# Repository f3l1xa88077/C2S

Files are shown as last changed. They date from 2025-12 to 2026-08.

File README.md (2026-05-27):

# CubeSat Camera System (C2S)
Relevant work for the PAST CubeSat 1 payload mission. This project focuses on developing a functioning prototype of the payload camera. The STM32U5 is used for low power performance and the image sensor is connected via DCMI.

The repository includes most aspects of the project including: documentation, hardware (Altium), mechanical 3D models, and software.

## How do I load a CubeIDE project?

The .gitignore has been modified to track critical files only, meaning most libraries and files will need to be generated again.

1. First, download the project locally: `git clone https://github.com/PerthAerospaceStudentTeam/C2S/tree/main`
2. Open the desired project in the STM32CubeIDE via: File>Import>'Projects from Folder or Archive'>Directory.
    - The project will be found in either the C2Sv0.1 or C2Sv1 directory.
3. Click the bullet icon to generate code
4. Click the hammer icon to build the project

If loaded successfully, the console should print the following to verify:

```
Finished building target: C2Sv0.1.elf
 
arm-none-eabi-size  C2Sv0.1.elf 
arm-none-eabi-objdump -h -S C2Sv0.1.elf  > "C2Sv0.1.list"
   text	   data	    bss	    dec	    hex	filename
 110972	    208	  50720	 161900	  2786c	C2Sv0.1.elf
Finished building: default.size.stdout
 
Finished building: C2Sv0.1.list

20:14:41 Build Finished. 0 errors, 0 warnings. (took 12s.137ms)

```

If any fatal errors are printed to the console, or the text in the output file is very low `text: 96` then you should address this before proceeding.

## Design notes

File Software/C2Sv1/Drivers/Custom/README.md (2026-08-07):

# C2Sv1.0 Custom Library

Overview of the custom libraries developed for the C2Sv1.0 payload, providing essential hardware abstraction and core functional interfaces.

## OV7670 Camera Module

...

## INA219BIDR Current Sense Amplifier

The INA219BIDR is a current sense amplifier (CSA) that allows you to monitor the real-time power/current consumption of the board.

### Core Variables

- `hi2c`: The I2C handle generated by CubeMX
- `INA219_HandleTypeDef`: A struct that tracks device configuration and calculated telemetry:
    - `*hi2c`: Pointer to the I2C handle
    - `current_lsb`: Calculated current LSB resolution used for unit conversion
    - `calibration`: Value written to the INA219 calibration register
    - `shunt_voltage`: Raw shunt voltage register value
    - `bus_voltage`: Raw bus voltage register value
    - `power`: Raw power register value
    - `current`: Raw current register value
    - `current_mA`: Converted load current in milliamperes (mA)
    - `power_mW`: Converted power consumption in milliwatts (mW)

### Basic Methods

| Function | Basic Description |
| :--- | :--- |
| `INA219_Setup(*INA219, *hi2c);` | Configures the chip based on settings in `INA219`. |
| `INA219_ReadAll(*INA219)` | Completes readings and conversions and stores results in `INA219`. |

### Basic Usage Example

```c
#include "ina219.h"

I2C_HandleTypeDef hi2c;
INA219_HandleTypeDef INA219_Chip;
INA219_Setup(&INA219_Chip, &hi2c);

// Read CSA Data
INA219_ReadAll(&INA219_Chip);

// Grab power (mW) and current (mA):
float power = INA219_Chip.power_mW;
float current = INA219_Chip.current_mA;

```

### Important Notes

- The INA219 gain and shunt resistance is defined in `config.h`.

## AT25xF2561C QSPI Flash Memory Driver

Custom STM32 HAL-based QSPI driver for the **Renesas AT25xF2561C** (256 Mbit / 32 MB) QSPI Flash memory chip. This driver abstracts low-level STM32 HAL QSPI commands into an intuitive API for reading, writing, and erasing data chunks specifically for C2S development.

### Core Variables

- `hospi`: The OctoSPI handle generated by CubeMX.
- `sCommand`: A command struct for OctoSPI functions.
- `QSPI_HandleTypeDef`: A struct that tracks chip information like,
    - `occupied_data`: How much data has already been written
    - `memory_size`: how many bytes the chip can hold
    - `ID_REG[3]`: The manufacturing ID
    - `*hospi`: Pointer to the OctoSPI handle
    - `*sCommand`: Pointer to the command struct
- `QSPI_DataBlock_HandleTypeDef`: A struct that tracks information for an image to be written to memory.
    - `data_size`: How large the data is in bytes
    - `*tx_pData`: Pointer to the data source
    - `*rx_pData`: Pointer to the data destination (where it will be read back into)
    - `address_block_start`: Where in QSPI the data starts
    - `address_block_end`: Where in QSPI the data ends

### Basic Methods

| Function | Basic Description |
| :--- | :--- |
| `QSPI_Init_Memory(*hospi, *sCommand, *QSPI_Memory)` | Configures the QSPI memory and populates `QSPI_Memory`. |
| `QSPI_Init_DataBlock(*DataBlock, data_size, *tx_pData, *rx_pData)` | Preps the image for transfer by populating `DataBlock` with the memory to be written `tx_pData` and the location where it will eventually be read back into `rx_pBuffer`.|
| `QSPI_Write_Data(*QSPI_Memory, *DataBlock)` | Writes `tx_pBuffer` to `QSPI_Memory`. |
| `QSPI_Read_Data(*QSPI_Memory, *DataBlock)` | Reads data into `rx_pBuffer` from `QSPI_Memory`. |
| `QSPI_Erase_Data(*QSPI_Memory, *DataBlock)` | Clears `DataBlock` from QSPI memory |

### Basic Usage Example

```c
#include "AT25xF2561C.h"

uint8_t tx_data[] = "IMAGE_DATA_001";
uint8_t rx_buffer[sizeof(tx_data)];

OSPI_HandleTypeDef hospi1;
QSPI_HandleTypeDef QSPI_Memory;
OSPI_RegularCmdTypeDef sCommand;
QSPI_DataBlock_HandleTypeDef DataBlock;

// Initialise driver hardware & configuration
QSPI_Init_Memory(&hospi1, &sCommand, &QSPI_Memory);

// Prepare data chunk (Source, Destination, Size)
QSPI_Init_DataBlock(&DataBlock, sizeof(tx_data), tx_data, rx_buffer);

// Write to memory
QSPI_Write_Data(&QSPI_Memory, &DataBlock);

// Do some stuff...

// Read back data
QSPI_Read_Data(&QSPI_Memory, &DataBlock);

// Clear data
QSPI_Erase_Data(&QSPI_Memory, &DataBlock);

```

### Important Notes

- The driver uses a **Last-In, First-Out (LIFO)** stack architecture managed by `occupied_data` inside the `QSPI_Memory` handle. It was designed around storing a single image, so if you store several items, make sure you abide by stack rules (writing/erasing in reverse order). You can read data from any position though.

- If you are finished with data, make sure to erase it, otherwise a memory leak will occur!

- At the time of `QSPI_Init_DataBlock`, you don't need to have specified `rx_pData` as it is only accessed when calling `QSPI_Read_Data`, if need be, you can leave it as `void`. The same goes for `tx_pData`.

- Data can be left in its original types as it is cast to the required type during read/write.

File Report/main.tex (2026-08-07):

\documentclass[10pt]{article}

% -----------------------
% Style Document
% -----------------------
\usepackage{style}

% -----------------------
% References
% -----------------------

\bibliography{Ref/ref}
\bibliography{Ref/stm}
\bibliography{Ref/misc}
\bibliography{Ref/datasheets}

% -----------------------
% Page Layout
% -----------------------
\pagecolor{white}
\color{black}
\geometry{a4paper, margin=1in}

% -----------------------
% Hyperref Setup
% -----------------------
\hypersetup{
    colorlinks=true,
    linkcolor=blue,
    urlcolor=cyan,
    pdftitle={CubeSat Camera System - Project Report},
    pdfpagemode=FullScreen,
}

% -----------------------
% Header/Footer Setup
% -----------------------
\pagestyle{fancy}
\fancyhf{}
\fancyhead[R]{Perth Aerospace}
% \fancyhead[C]{\bfseries \textcolor{red}{CONFIDENTIAL DO NOT RELEASE}}
\fancyhead[L]{\leftmark}
\fancyfoot[C]{C2S - Project Report}
\fancyfoot[L]{Page \thepage}
\renewcommand{\headrulewidth}{0.4pt}
\renewcommand{\footrulewidth}{0.4pt}

% -----------------------
% Begin Document
% -----------------------
\begin{document}

% -----------------------
% COVER PAGE
% -----------------------
\pagecolor[HTML]{0025A9}
\begin{titlepage}
    \centering
    \color{white}
    \vspace*{2cm}
    
     % Replace with your team logo
    
    \vspace{2cm}
    {\LARGE\bfseries Project Report\par}
    \vspace{0.5cm}
    {\Huge\bfseries CubeSat Camera System (C2S)\par}
    % \vspace{1cm}
    % {\Huge\bfseries \textcolor{red}{CONFIDENTIAL}\par}
    % {\Huge\bfseries \textcolor{red}{DO NOT RELEASE}\par}
    
    \vspace{2cm}
    {\large Abbott F. \quad | \quad Perth Aerospace Student Team\par}
    \vspace{0.25cm}
    {\large Mission Department \quad | \quad CubeSat 1 Mission\par}

    \vspace{3cm}
    This document presents all the considerations and processes towards developing the CubeSat Camera System, an undergraduate student-based project as part of the Perth Aerospace Student Team.
    The project served as a strong platform to develop sophisticated understandings of various camera subsystems.
    
    \vfill
    {\large \today \par}
\end{titlepage}

% -----------------------
% Preliminary and Reset Style
% -----------------------
\pagecolor{white}
\color{black}
\pagestyle{fancy}
\pagenumbering{roman}

% -----------------------
% Version History
% % -----------------------
% \newpage
% \section*{Document Version History}
% \begin{table}[H]        
%     \centering
%     \begin{tabular}{|l|l|p{8cm}|}
%         \hline
%     \textbf{Doc. Version} & \textbf{Date} & \textbf{Change} \\
%     \hline
%     v0.0 & Aug. 25 & Added introduction \& project details \\
%     \hline
%     v0.1 & Aug. 25 & Added version 0 system planning \\
%     \hline
%     v0.2 & Sep. 25 & Version 0 content written \\
%     \hline
%     v1.0 & Dec. 25 & Report appearance reformatted and restructured content \\
%     \hline
%     v1.1 & Mar. 26 & Content for Version 0.1 written \\
%     \hline
%     v2.0 & Apr. 26 & Report restructured, with detail added to lacking sections \\
%     \hline
%     v2.1 & May. 26 & Version 1.0 schematic content written and heading 4 added \\
%     \hline
%     \end{tabular}
% \end{table}

% -----------------------
% TOC
% -----------------------
\newpage

% 1. Ensure tocdepth is 4 (includes subsubsubsections)
\setcounter{tocdepth}{4}

% 2. Redefine how the standard paragraph entry is handled in the TOC
\makeatletter
% If the entry is a standard 'paragraph', do nothing (swallow it)
% If it's your 'subsubsubsection', it will use the \l@subsubsubsection we defined
\renewcommand{\l@paragraph}[2]{} 
\makeatother

\makeatletter
% 1. Link the titlesec class to tocloft
\newcommand{\l@subsubsubsection}{\@dottedtocline{4}{6em}{5em}}

% 2. Create the missing lengths that tocloft doesn't make automatically
\newlength{\cftsubsubsubsecindent}
\newlength{\cftsubsubsubsecnumwidth}
\makeatother

% 3. Spacing between entries
\setlength{\cftbeforesecskip}{2em}
\setlength{\cftbeforesubsecskip}{0.5em}
\setlength{\cftbeforesubsubsecskip}{0.25em}

% 4. Set Indentations (Staircase effect)
\setlength{\cftsecindent}{0em}          % Level 1
\setlength{\cftsubsecindent}{2em}       % Level 2
\setlength{\cftsubsubsecindent}{4em}    % Level 3
\setlength{\cftsubsubsubsecindent}{6em} % Level 4 (Your new level)

% 5. Set Number Widths
\setlength{\cftsecnumwidth}{2em}
\setlength{\cftsubsecnumwidth}{3em}
\setlength{\cftsubsubsecnumwidth}{4em}
\setlength{\cftsubsubsubsecnumwidth}{5em}

\tableofcontents

% -----------------------
% Table of Abbreviations
% -----------------------
\newpage
\section*{Table of Abbreviations}
    \import{Chapters/Pre/}{Abbreviations.tex}

% -----------------------
% Summary
% -----------------------
\newpage
\section*{Summary}
    \import{Chapters/Pre/}{Summary.tex}

% -----------------------
% MAIN CONTENT
% -----------------------
\newpage
\justifying
\clearpage
\pagenumbering{arabic}

\section{Introduction}\label{sec:intro}
    \import{Chapters/Intro/}{Intro.tex}

\newpage \section{C2Sv0}\label{sec:c2sv0}
    \import{Chapters/v0/}{v0.tex}

\newpage \section{C2Sv0.1}\label{sec:c2sv0.1}
    \import{Chapters/v0.1/}{v0.1.tex}

\newpage \section{C2Sv1}\label{sec:c2sv1}
    \import{Chapters/v1/}{v1.tex}

% \clearpage
% \addcontentsline{toc}{section}{References}
% \printbibliography

% \clearpage
% \appendix
% \section*{Appendices}\label{sec:appendices}
% \addcontentsline{toc}{section}{Appendices}
% \setcounter{section}{0}
%     \import{Chapters/Appendices/}{Appendices.tex}

\end{document}

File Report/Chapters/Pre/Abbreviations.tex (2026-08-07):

\begin{abbreviations}
\item[CSA] Current Sense Amplifier
\item[C2S] CubeSat Camera System
\item[LDO] Low Drop Out
\item[USB] Universal Serial Bus
\item[PAST] Perth Aerospace Student Team
\item[LEO] Low Earth Orbit
\item[PCB] Printed Circuit Board
\item[BGA] Ball Grid Array  
\item[NIR] Near Infra-Red
\item[CMOS] Complementary Metal Oxide Semiconductor
\item[CIS] CMOS Image Sensor
\item[FPGA] Field Programmable Gate Array
\item[LVDS] Low Voltage Differential Signalling
\item[IC] Integrated Circuit 
\item[ASIC] Application Specific Integrated Circuit
\item[DSP] Digital Signal Processor
\item[MCU] Micro Controller Unit
\item[SDRAM] Synchronous Dynamic Random Access Memory 
\item[SD] Secure Digital
\item[uSD] microSD 
\item[SDMMC] Secure Digital MultiMediaCard
\item[TCXO] Temperature Compensated Crystal Oscillator
\item[VDD] Voltage Drain Drain
\item[GND] Ground
\item[DGND] Digital Ground
\item[AGND] Analog Ground 
\item[GPIO] General Purpose Input Output
\item[MOSFET] Metal Oxide Semiconductor Field Effect Transistor
\item[CLK] Clock
\item[LSE] Low Speed External
\item[HSE] High Speed External
\item[LPS] Local Power Supply
\item[FPC] Flexible Printed Circuit
\item[NC] No Connect
\item[SMPS] Switched-Mode Power Supply
\item[DCMI] Digital Camera Media Interface
\item[CSI-2] Camera Serial Interface-2
\item[AT\&MWA] Advanced Technology and Manufacturing Western Australia
\item[SPI] Serial Peripheral Interface
\item[QSPI] Quad Serial Peripheral Interface
\item[OSPI] Octal Serial Peripheral Interface
\item[HiSPI] High-Speed Serial Pixel Interface
\item[I2C] Inter Integrated Circuit
\item[ADC] Analog to Digital Converter 
\item[LCD] Liquid Crystal Display
\item[EPS] Electrical Power Systems
\item[PSSR] Power Supply Rejection Ratio
\item[BOM] Bill Of Materials  
\item[C2I] C2S Camera Interface
\end{abbreviations}

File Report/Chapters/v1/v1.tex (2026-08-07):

Version 1 (v1) of C2S focuses on developing a CubeSat prototype - an early functional model built to test functionality. One major difference in this version explores a top-down systems-engineering approach, something that lacked in versions 0 and 0.1. Previously, all systems were developed in parallel to each other, meaning my component selection for the MCU was occuring at the same time I was selecting the CMOS Image Sensor (CIS). At first glance, this may seem fine, but this parallel approach fails to consider the system requirements. The CIS is the main component that everything should be designed around, not the other way around. To avoid this problem, certain goals were put in place to ensure this version was mission-oriented:

\begin{enumerate}
    \item \textbf{Systems Planning}
    \\ Consulting with manufacturers, techical documentation, and Subject Matter Experts (SMEs) to develop a trade study. Identify system requirements, map connections, data flows, and interactions between different subsystems to ensure all parts are compatible.
    \item \textbf{Comms \& Mechanical Capabilities}
    \\ Understanding and defining the camera's CubeSat limitations - dimensions, download rate, etc.
    \item \textbf{CIS Agreements}
    \\ Ensuring Non Disclosure Agreements (NDAs) are signed, so any proprietary information can be easily accessed at any time.
    \item \textbf{Component Selection}
    \\ Selecting all other components based on the system requirements.
    \item \textbf{Development}
    \\ Creating schematics, PCBs, manufacturing, etc.
\end{enumerate}

These goals were developed from my experiences of what had and hadn't worked with the previous versions, so they may not be perfect, but these are what I found to be the most important steps in camera development. Additionally, it makes writing and, in your case, reading, a lot easier to digest.

% -----------------------
% Systems Planning
% -----------------------
\subsection{Systems Planning}\label{sec:v1-planning}

    \subsubsection{Trade Study}
        \subimport{./Planning/}{Trade.tex}

    \subsubsection{System Requirements}\label{sec:v1-requirements}
        \subimport{./Planning/}{Requirements.tex}

    \subsubsection{Systems Integration Diagram}
        \subimport{./Planning/}{Planning.tex}

    \subsubsection{Capabilities}
        \subimport{./Planning/}{Capabilities.tex}

% -----------------------
% Schematic and Component Selection
% -----------------------
\subsection{Schematic Design \& Component Selection}\label{sec:v1-schematic}

    \subsubsection{MCU}\label{sec:v1-schematic-mcu}
        \subimport{./Hardware/Schematic/}{MCU.tex}

    \subsubsection{Sensor}\label{sec:v1-schematic-sensor}
        \subimport{./Hardware/Schematic/}{Sensor.tex}

    \subsubsection{Memory}
        \subimport{./Hardware/Schematic/}{Memory.tex}

    \subsubsection{microSD}\label{sec:v1-microSD}
        \subimport{./Hardware/Schematic/}{microSD.tex}

    \subsubsection{Connectors}\label{sec:v1-connectors}
        \subimport{./Hardware/Schematic/}{Connectors.tex}

    \subsubsection{Power}\label{sec:v1-schematic-power}
        \subimport{./Hardware/Schematic/}{Power.tex}

    \subsubsection{USB-C}
        \subimport{./Hardware/Schematic/}{USBC.tex}

    \subsubsection{STLINK}\label{sec:v1-schematic-stlink}
        \subimport{./Hardware/Schematic/}{STLINK.tex}

    \subsubsection{Clocks}
        \subimport{./Hardware/Schematic/}{Clocks.tex}

    \subsubsection{Button}
        \subimport{./Hardware/Schematic/}{Button.tex}

    \subsubsection{LEDs}
        \subimport{./Hardware/Schematic/}{LEDs.tex}

    \subsubsection{Test Points}
        \subimport{./Hardware/Schematic/}{TP.tex}

% -----------------------
% PCB Design
% -----------------------
\subsection{PCB Design}\label{sec:v1-pcb}

    The following sections will exclusively refer to C2Sv1.0 processor PCB. The bridge PCB consisted of a 2-layer PCB designed alongside the considerations of the processor PCB i.e., the same design considerations applied to both boards.

    \subsubsection{Stackup}
        \subimport{./Hardware/PCB/}{Stackup.tex}

    \subsubsection{Layout}\label{sec:v1-layout}
        \subimport{./Hardware/PCB/}{Layout.tex}

    \subsubsection{Routing}\label{sec:v1-routing}
        \subimport{./Hardware/PCB/}{Routing.tex}

    \subsubsubsection{Coupling}\label{sec:v1-coupling}
        \subimport{./Hardware/PCB/}{Coupling.tex}

    \subsubsection{Vias}
        \subimport{./Hardware/PCB/}{Vias.tex}

    \subsubsection{Power Pad}
        \subimport{./Hardware/PCB/}{Power Pad.tex}

    \subsubsection{Silkscreen}
        \subimport{./Hardware/PCB/}{Silkscreen.tex}

    \subsubsection{Mounting}
        \subimport{./Hardware/PCB/}{Mounting.tex}

% -----------------------
% Manufacturing
% -----------------------
\subsection{Manufacturing}\label{sec:v1-manufacturing}
    \subimport{./Manufacturing/}{Manufacturing.tex}

% -----------------------
% Software
% -----------------------
\subsection{Software}\label{sec:v1-software}
    \subimport{./Software/}{Software.tex}

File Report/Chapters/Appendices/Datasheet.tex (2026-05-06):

\subsection{Image Sensors}

\subsubsection{AR0141 Sensor}
    \begin{indentedfigure}
        
        \caption{Absolute maximum ratings of AR0141CS2M00SUEA0-DPBR found on the component datasheret, Table 26}
        \label{fig:ar0141-max}
    \end{indentedfigure}

    \begin{indentedfigure}
        
        \caption{Typical configuration for parallel pixel data interface on AR0141CS2M00SUEA0-DPBR.}
        \label{fig:ar0141-parallel-config}
    \end{indentedfigure}

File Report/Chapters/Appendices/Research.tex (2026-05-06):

% -----------------------
% WEEK 1
% -----------------------

\section{Imaging Physics and Optics}

\subsection{Focal length}

\textbf{Focal length} describes how strongly a lens focuses or diverges light. A large focal length indicates that light is being bent gradually, whereas a shorter focal length bends light at sharper angles.
A positive focal length means that the light is converging, and a negative focal length means that the light is diverging. In most photography and telescopy, longer focal length results in a greater magnification of the subject and wider focal lengths create a wider angle of view.
\nl
For thin convex lenses, the focal length can easily be measured, where the distance from the object to the lens $u$, the distance from the lens to the image $v$, and the focal length $f$ are related by \(1/f = 1/u + 1/v\).
The lens is moved until a sharp image is formed on the screen i.e., $1/u$ becomes negligible. At this point, the focal length is given by $f\approx v$.
Determining the focal length of a concave lense is more difficult abnd requires a much more systematic approach.
\nl
\begin{indentedfigure}
    \centering
    
    \caption{Thick lens diagram}
    \label{fig:lens-diagram}
\end{indentedfigure}
For a thick lens, or systems consisting of several lenses, there are several related concepts that are referred to as focal lengths:
\begin{itemize}
    \item \textbf{Effective focal length (EFL)}: The EFL is the inverse of the optical power of an optical system, and is the value used to calculate the magnification of the system. The imaging properties of the optical system can be modelled by replacing the system with an ideal, thin lens with the same EFL. It also provides a simple method for finding the nodal points without tracing rays.
    \item \textbf{Fron focal length (FFL)}: The FFL $f$ is the distance from the front focal point $F$ to the front principal plane $H$
    \item \textbf{Rear focal length (RFL)}: The RFL, $f'$, is the distance from the rear principal plane $H'$ to the rear focal point $F'$.
    \item \textbf{Front focal distance (FFD)}: The FFD, $s_F$, is the distance from the front focal point of the system, $F$, to the vertext of the first optical surface $S_1$. Sometimes this is referred to as the front focal length.
    \item \textbf{Back focal distance (BFD)}: BFD, $s'_F$, is the distance from the vertex of the last optical surface of the system $S_2$ to the rear focal point $F'$. This is sometimes referred to as the back focal length.
\end{itemize}
For an optical system in the air, the above are all the same and may be called the focal length.
\nl
For optical systems in mediums other than air or vacums, the focal length changes with the refractive index of the mediums, however, this project will not focus on this specific topic.

Camera lens focal lengths are usually specified in millimetres (mm), but some older lenses are marked with centimetres (cm) or inches.
\textbf{Focal length} $f$ and \textbf{field of view} of a lens are inversely proportional. For a standard recilinear lens,
\begin{equation}
    FOV = 2\arctan(\frac{x}{2f})
    \label{eq:fov}
\end{equation}
where $x$ is the width of the film or imaging sensor. When a photographic lens is set to "infinity", its rear principal plane is separated from the sensor or film, which is then situated at the focal plane, by the lens' focal length. Objects far away from the camera then produce sharp images on the sensor or film, which is also at the image plane.
\nl
To render closer objects in sharp focus, the lens must be adjusted to increase the distance between the rear principal plane and the film, to put the film at the image plane. The focal length $f$, the distance from the front principal plane to the object to photograph $s_1$, and the distance from the rear principal plane to the image plane $s_2$ are then related by \(1/s_1 + 1/s_2 = 1/f\).
As $s_1$ is decreased, $s_2$ must be increased. For example, consider a normal lens for a 35mm camera with a focal length of $f=50$mm. To focus a distant object ($s_1 \approx \infty$), the rear principal plane of the lens must be located at a distance $s_2=50$mm from the film plane, so that it is at the location of the image plane. To focus an object 1m away ($s_1 = 1,000$mm), the lens must be moved 2.6mm farther away from the film plane, to $s_2=52.6$mm.

\subsection{Optical power}

The \textbf{optical power} of a lens or curved mirror is a physical quantity equal to the reciprocal of the focal length, expressed in metres. A dioptre is its unit of measurement iwth dimension of reciprocal length, equivalent to one reciprocal metre, 1 dioptre = 1$m^{-1}$. E.g., a 2-dioptre lens brings parallel rays of light to focus at $1/2$ metre. A flat window has an optical power of zero dioptres, as it does not cause light to converge or diverge.

\subsection{Field of view}
The \textbf{field of view (FOV)} is the angular extent of the observable world that is seen at any given moment. In photography, the FOV is that part of the world that is visible by the camera at a particular position and orientation in spacel objects outside the FOV when the picture is taken are not recorded in the photograph. It is most often expressed as the angular size of the view cone, as an angle of view. For a normal lens focused at infinity, the diagonal FOV can be calculated with \ref{eq:fov}.
\nl
FOV is critically important in space imaging because it directly impacts what, how much, and how well a spacecraft or satellite can observe. Wider FOVs capture larger areas, whereas narrower FOVs capture more detail over a smaller area. For CubeSat applications, the FOV directly impacts the design on the system because a narrower FOV requires a longer focal length and a longer lens. If the FOV is too narrow, then deployable instruments must be investigated to break the 10x10x10cm constraint.
Wider FOVs don't require many manouvres to capture images, but narrow FOVs require precise movements to capture the correct area. Both have benefits and drawbacks.

\subsection{Aperture}
In optics, the aperture of an optical system is the hole or opening that primarily limits light propagated through the system. An optical system typically has many structures that limit pencils of light. These structures may be the edge of a lens, or a ring or other fixture that holds an optical element in place or may be a special element such as a diaphragm placed in the optical path to limit the light admitted by the system.
In general, these structures are called stops, and the aperture stop is the stop that primarily determines the cone of rays that an optical system accepts. As a result, it also determines the ray cone angle and brightness at the image point. The aperture stop generally depends on the object point location; on-axis object points at different lateral locations at the same object plane have different aperture stops (vignetted). In practice, many object systems are designed to have single aperture stop at designed working distance and field of view.
\nl
The size of the aperture stop determines the amount of light admitted by an optical system. The aperture stop also affects other optical system properties:
\begin{itemize}
    \item The opening size of the stop is one factor that affects the \textbf{depth of field (DOF)}. A smaller stop (larger f number) produces a longer DOF because it only allows a smaller angle of the cone of light reaching the image plane so the spread of the image of an object point is reduced. A longer DOF allows objects at a wide range of distances from the viewer to be in focus at the same time.
    \item The stop limits the effect of optical aberrations by limiting light such that the light does not reach edges of optics where aberrations are usually stronger than the optics centers.
    \item The stop determines whether the image will be vignetted. Larger stops can cause the light intensity reaching the film or detector to fall off toward the edges of the picture, especially when, for off-axis points, a different stop becomes the aperture stop by virtue of cutting off more light than did the stop that was the aperture stop on the optic axis.
    \item The stop location determines the telecentricity (the entrance or exit pupil, or both, at infinity). If the aperture stop of a lens is located at the front focal plane of the lens, then it becomes image-space telecentricity, i.e., the lateral size of the image is insensitive to the image plane location. If the stop is at the back focal plane of the lens, then it becomes object-space telecentricity where the image size is insensitive to the object plane location. The telecentricity helps precise two-dimensional measurements because measurement systems with the telecentricity are insensitive to axial position errors of samples or the sensor.
\end{itemize}
In astronomy, the opening diameter of the aperture stop (called the aperture) is a critical parameter in the design of a telescope. Generally, you would want the aperture to be as large as possible, to collect the maximum amount of light from the distant objects being imaged. The size of the aperture is limited, however, in practice by considerations of its manufacturing cost and time and its weight, as well as prevention of aberrations (as mentioned above).
\nl
In photography, the aperture stop of a photographic lens can be adjusted to control the amount of light reaching the image sensor. In combination with variation of shutter speed, the aperture size will regulate the image sensor's degree of exposure to light (this is called the \href{https://photographylife.com/what-is-exposure-triangle}{exposure triangle}). A device called a diaphragm usually serves as the aperture stop and controls the aperture. The diaphragm serves much like the iris of the eye. Reducing the aperture size provides less light to the sensor and increases the depth of field, which describes the extent to which subject matter lying closer than or farther from the actual plane of focus appears to be in focus.
The lens aperture is usually specified as an f-number, the ratio of focal length to effective aperture diameter. In photography, \textit{one f-stop} refers to a factor of $\sqrt{2}$ change in f-number which corresponds to a $\sqrt{2}$ change in aperture diameter, which in turn corresponds to a factor of 2 change in light intensity (by a factor 2 change in the aperture area).
The amount of light captured by an optical system is proportional to the aera of the entrance pupil that is the object space-side image of the aperture of the system, equal to:
\[
Area = \pi (\frac{D}{2})^2 = \pi (\frac{f}{2N})^2
\]
Where the two equivalents are related by the f-number $N=f/D$, with focal length $f$ and entrance pupil diameter $D$.

\subsection{Key Trade-Offs in Earth Observation Imaging}
The interplay between motion blur, exposure time, and depth of field is a critical consideration in Earth observation imaging. Adjusting one parameter often impacts the others, necessitating a balance to achieve optimal image quality.
\nl
\textbf{Motion Blur vs. Exposure Time}: Longer exposure times capture more light, reducing noise, but they increase the risk of motion blur, especially in satellite imaging where relative motion is significant. Conversely, shorter exposure times minimise motion blur but may lead to darker images since they capture less light. The maximum exposure time to minimise motion blur can be found by \(t=\frac{rc}{v}\), where $r$ is the spatial resolution, $c$ is a factor of the motion blur (between 0 and 1) and $v$ is the speed of the CubeSat.
\nl
\textbf{Exposure Time vs. Noise}: Reducing exposure time to combat motion blue can result in increased image noise, as the sensor has less time to collect photons. This trade-off is particularly challenging in low-light conditions or when high image clarity is required.
\nl
\textbf{Aperture vs. Exposure}: A wider aperture allows more light, enabling shorter exposure times and reducing motion blur. However, it decreases the depth of field, potentially causing parts of the image to be out of focus. A narrower aperture increases depth of field but required longer exposure times.
\nl
Advanced sensors with higher sensitivity (quantum efficiency) can mitigate some of these trade-offs by allowing shorter exposure times without significantly increasing noise. Techniques such as motion compensation and image stabilisation can help reduce the effects of motion blur without altering exposure settings. Image processing algorithms can correct for certain artifacts like noise and blur, but they have limitations and cannot fully compensate for suboptimal capture settings.

\subsection{C, CS and S-Mount Camera Lenses}
Lens mounts are the mechanical interfaces that attach a lens to a camera and set the correct distance for focus. When designing compact or modular camera systems, three primary lens mount types are commonly considered: \textbf{M12 (S-Mount), CS-mount}, and \textbf{C-mount}. Each has distinct mechanical and optical characteristics, making them suitable for different use cases.
\nl
The \textbf{M12 mount}, also known as the \textbf{S-mount}, is the smallest and lightest of the three. It uses a 12mm diameter thread and has no fixed flange focal distance (FFD), typically relying on adjustable back-focus. M12 lenses are compact and inexpensive, making them ideal for small embedded systems like drones or hobby cameras. However, their image quality is generally lower due to smaller optics, and they usually support sensor formats up to 1/2" or 1/1.8".
\nl
The \textbf{CS-mount} is a more robust, standardised system commonly used in CCTV and industrial vision. It shares the same thread as the C-mount (1"-32 UN), but has a shorter FFD of 12.5mm, which means lenses sit closer to the sensor. CS-mount cameras can use both CS and C-mount lenses, giving it some flexibility. These lenses support larger sensors and generally offer better image quality than M12 lenses.
\nl
The \textbf{C-mount} is the most optically capable of the three, also using the 1"-32 UN thread0 but with a 17.526mm FFD. C-mount lenses are larger, heavier, and typically of higher optical quality, supporting sensor sizes up to 1" or more. They are often used in scientific imaging, space optics, and high-end industrial systems. However, their size and mass can be a limiting factor in space-constrained environments.

\subsection{Autofocus vs. Fixed-focus Lenses}
Embedded vision systems rely heavily on the capabilities of their lenses. The lens's optical properties, such as its focal length, aperture, and FOV, dictate the clarity, depth, and breadth of the captured image. These parameters, along with sensor size and resolution, directly impact the systems' ability to analyse and interpret visual data.
\nl
A \textbf{fixed-focus lens} comes with a determined and unchangeable focal length. Once set, this focus remains constant and doesn't adjust based on changes in the scene or the distance of the target object. Such lenses are calibrated during the design or manufacturing phase for a specific application or distance, ensuring optimal clarity for that designated range.
Fixed-focus lenses are advantageous in scenarious that demand consistent and predictable imaging results. When objects are presented at a consistent distance from the camera, fixed-focus lenses offer stability and repeatability. For the CubeSat mission, it is highly likely we will used a fixed-focus lens since we will only be taking one type of image at a consistent orbital distance.
\nl
An \textbf{autofocus (AF)} lens can automatically adjust its focus based on the scene. Unlike manual focus lenses, which require a predefined focus set during the design or intial setup, autofocus lenses dynamically adjust to ensure the targeted subject or region of interest remains sharp. It is achieved through sensors and algorithms that detect the optimal focus point, allowing the lens to modify its focus in real time.
AF lenses offer a high level of adaptability and accuracy in embedded vision systems, ranging from industrial automation to medical devices. They can continuously adjust to provide sharp images.
\nl
The selection criteria for AF vs. fixed-focus lens includes:
\begin{itemize}
    \item \textbf{Proximity}: The distance between the camera and target plays a crucial role in selecting a lens, impacting the clarit and precision of captured images. AF lenses are preferable for fluctuating distances, especially from a close 10cm to an endless range, allowing dynamic adjustments. However, a fixed-focus lens is better suited for a set distance, ensuring consistent imagery without any adjustments.
    \item \textbf{Depth of Field (DoF)}: Cameras with autofocus lenses offer broader field depths than their fixed-focus counterparts. But sometimes, depending on the use case, a fixed-focus camera lens may be required, as some applications do not need broader field depths.
    \item \textbf{Lighting Conditions}: This directly influences the clarity of photos. Autofocus lenses perform better under low lighting, with some fine-tuning to provide further clarity. However, under brightly lit conditions, a fixed-focus camera lens can offer clear images within its preset range.
    \item \textbf{Rate of capture}: Fixed-focus lenses typically work faster than their AF counterparts, as they lack the need for focus adjustments. Their design prioritises speed over adaptability, making them efficient for certain tasks. Consequently, if an application demands fast image cpature without interruptions, a fixed-focus lens is the recommended choice. It ensures consistent, rapid imaging without the potential lag of autofocus lens adjustments.
    \item \textbf{Adaptability}: The camera lens' versatility is also a deciding factor. Autofocus lenses perform better in low-light scenarios, with some customisation. However, fixed-focus camera lenses can offer clear images within their preset range under brightly lit conditions, where light is stable and abundant.
\end{itemize}
With the CubeSat mission in mind, these considerations are critically important:
\begin{itemize}
    \item \textbf{Size and Weight}: AF lenses require motors, actuators, and additional housing, all of which increase the overall size and mass. Fixed-focus lenses are typically much smaller and lighter.
    \item \textbf{Power Consumption}: AF systems consume electrical power to operate motors and sensors needed for focusing. Fixed lenses use no power once installed.
    \item \textbf{Reliability}: Moving parts in AF lenses can jam, degrade, or fail over time. A foxed-focus system is mechanically simple and has fewer points of failure, making it much more suitable for long-duration, unattended missions.
    \item \textbf{Launch Survivability} The vibration during rocket launch can damage sensitive optical systems. AF components may loosen or break. Fixed-focus lenses are more robust and more likely to survive launch intact.
    \item \textbf{Autonomy and Complexity}: AF systems require logic to detect blur, estimate distance, and control motors. This demands more computing resources and software development. Fixed-focus lenses avoid this entirely, simplifying the onboard system and reducing potential bugs.
\end{itemize}
As previously mentioned, it is very likely the CubeSat mission will utilise a fixed-focus lens. Future missions may provide scope to consider AF systems, however, since the projected outcomes for the first CubeSat mission involve functionality of the core sub-systems, a fixed-focus lens will be best suited to the mission.

\subsection{Wide and vs. Telephoto Imaging}
\textbf{Telephoto imaging} refers to a narrow FOV with high magnification (useful for capturing small details or distant targets), whereas \textbf{wide-angle imaging} provides a broader FOV (useful for capturing a larger area).
\nl
Telephoto lenses require a much larger focal length which is difficult to achieve in a CubeSat form factor. There have recently been \href{https://digitalcommons.usu.edu/cgi/viewcontent.cgi?referer=&httpsredir=1&article=3059&context=smallsat}{developments} into deployable telephoto lenses to achieve extremely high levels of detail up to 1 metre per pixel. These missions can typically use a 2U or larger form factor, so reaching a relatively high level of spatial resolution (50-100 metres per pixel) is a strong possibility for the CubeSat mission. Deployable telescopes may be out of scope for this first CubeSat mission, however, they do demonstrate that the task is possible.
Since longer focal lengths require a higher frame stability, more power may need to be directed to the ADCS. Telephoto imaging means the camera must be pointed very precisely at the target. Error in attitude can cause motion blur, data loss or missing the target entirely. Achieving this requires a longer stabilisation time after manouvres to confirm attitude.
Custom telephoto lens systems require more planning, budget, stricter testing and longer development times because of the increased scope.
\nl
\textbf{Wide angle lenses} have a much shorter focal length and their optical systems are much more compact. The wider FOV loses detail since the spatial resolution is much larger, however, they capture a larger area.
These lenses tolerate pointing errors because of the low spatial resolution. If the CubeSat isn't facing the target by a couple degrees, or is slowly rotating, the image will most likely be unaffected because the wide FOV tolerates more errors e.g., accidentally pointing at Mandurah instead of Perth doesn't matter if we are capturing an image from Esperance to Shark Bay.
Additionally, COTS wide angle cameras are cheap, small and readily available which will make integration much easier.
\nl
Since the file size and thermal management of both camera systems would be similar, it is not a critical comparison consideration.

\subsection{Optical distortions and corrections}
Distortion is specified as a percentage of the field height. Typically, $\pm 2\%$ to $3\%$ distortion is unnoticed in a vision system if measurement algorithms are not used. In simple lenses, there are two main types of distortion: negative, barrel distortion, where points in the FOV appear too close to the center; and positive, pincushion distortion, where points are too far away. Barrel and pincushion refer to the shape of the field when distorted, shown in \ref{fig:lens-distortion}.
\begin{indentedfigure}
    \centering
    
    \caption{An illustration of positive and negative distortion.}
    \label{fig:lens-distortion}
\end{indentedfigure}
These are usually referred to as \textbf{geometric distortions}, because straight lines appear curved or displaced especially at wide angles or at the edges of the FOV.
Distortion is calculated simply by relating the actual distance (AD) to the predicted distance (PD) of the image using \ref{eq:distortion}.
\begin{equation}
D(\%)=\frac{AD-PD}{PD}\times100\%
    \label{eq:distortion}
\end{equation}
These usually occur when the magnification decreases with distance from the center and is common in wide-angle and cheap lenses. Fortunately, some software algorithms like OpenCV's undistort() can provide optical correction (some applications such as Photoshop and Matlab have lens profiles in the software).
\nl
\subsubsection{Fisheye Distortion}
\textbf{Fisheye Distortion} is an extreme wide-angle effect where lines are heavily cirved, giving a hemispherical apperance. This is usually intentional for fish-eye lenses to capture extremely wide FOVs of $>160$\textdegree. Sometimes the effect is desirable, but it can be correct via software remapping using known distortion models (e.g., Photoshop has options to reverse fish-eye lens effects).
\nl
Optical aberrations are performance deviations from a perfect, mathematical model. It is important to note that they are not cause by manufacturing flays, physical, optical, nor mechanical. Rather, they are inherent in lens design and are due to diffraction, refraction, and the wave nature of light. As such, there is no perfect lens.
Effects from various aberrations in a lens design are ultimately seen in performance and affect modulation transfer function (MTF), spot size, telecentricity, DOF, and others. Aberration theory is an abstract and complex subject. Understanding how aberrations affect performance is important for success with an application.
Whilst aberration theory is a vast subject, basic knowledge of a few fundamental concepts can ease understanding: spherical, astigmatic, field curvature and chromatic.
\nl
\subsubsection{Spherical Aberration}
\textbf{Spherical Aberration} refers to rays focusing at different distances depending on where they interact with the lens and is a function of aperature size. To describe spherical aberration, the incident angle of light must be known. This angle occurs where light rays strike the curved surface of a lens and is the angle between the ray and the surface. The steeper the incident angle, the more light will be refracted.
\begin{indentedfigure}
    \centering
    
    \caption{An example of spherical aberration. The light incident upon the edges of the lens focuses more quickly due to their higher angle of incidence. Note that rays closer to the optical axis (smaller angle of incidence refract less).}
    \label{fig:spherical-aberration}
\end{indentedfigure}
\ref{fig:spherical-aberration} shows that as the parallel rays in object space collide with the lens, the incident angle increases the farther up they hit on the lens's surface. Image quality from the lenses with large apertures are more likely to suffer from spherical aberration, because of this larger angle of incidence. Lenses that suffer from spherical aberration can be improved by increasing the f-stop by closing the iris. Closing the iris too much causes diffraction to limi performance sooner. Optical designs that include high index glass or additional elements are used to correct spherical aberration in a fast (small f-stop) lens; these designs reduce the amount of refraction at each surface and, with it, the amount of spherical aberration. However, this increases the size, weight, and cost of the lens assembly.
\nl
\subsubsection{Astigmatism}
\textbf{Astigmatism} is a function of field angles. To summarise, astigmatic aberration occurs when a lens must perform over a wide field, but the performance in the direction of the field is reduced compared to the performance orthogonal to the field (either sagittal or tangential, respectfully). If one looks at a series of bars that are half horizontal (tangential) and half vertical (sagittal), the bars in one direction will be in focus, but the bars in the other will be out of focus.
\begin{indentedfigure}
    \centering
    
    \caption{Off-axis asymmetry. Note that the tangential and sagittal points of focus are different.}
    \label{fig:astigmatism}
\end{indentedfigure}
This is caused by the fact that the rays that are away from the center of the object, do not pass through rotationally symmetric surfaces like the on-axis rays do in \ref{fig:astigmatism}. To correct this, two things must occur: lens designs must be symmetric about the aperture and field rays must have low incident angles. Keeping a design symmetric leads to forms that are like a double gauss lens. Note that symmetric designs prevent the use of telephoto or reverse telephoto designs, which can cause long focal length designs to be large and short focal length designs to have small back focal lengths. Reducing the angles of incidence, much like for spherical aberration, requires higher index glasses and additional elements, leading to an increase in lens size, weight, and cost. The simplified definition used here intentionally combines the effects of astigmatism and coma for ease of understanding.
\nl
\subsubsection{Field Curvature}
\textbf{Field Curvature} is the aberration that describes the amount in which the image plane curves due to the curvature in the lens design. This aberration is caused by the sum of the focal lengths of the lens elements in the system (multiplied by the refractive indices) not equalling zero. If the sum is positive (typical for an imaging lens), the image plane will have a concave curvature. Since curving the image plane is almost never an option for a machine vision lens, the optical designer must insert negative powered corrective elements to reduce this sum. This makes lenses longer and forces a negative lens to be close to the image plane, reducing the lens's back focal length.
\begin{indentedfigure}
    \centering
    
    \caption{A field curvature example showing the non-planer surface of best focus.}
    \label{fig:curvature}
\end{indentedfigure}
\subsubsection{Chromatic aberration}
\textbf{Chromatic aberration} occurs when light of different wavelengths focus at different points since the refractive index of glass varies based on the wavelength of light. Lenses using longer wavelengths of light have relatively longer focal lengths than lenses using shorter wavelengths. Because the dispersion of a glass determines the refractive power of the glass at different wavelengths, chromatic aberration can be removed by designing an imaging lens that contains both positive and negative lenses made using glasses with different dispersions. This is shown in \ref{fig:chromatic}, which compares a singlet to an achromatic doublet lens.
\begin{indentedfigure}
    \centering
    
    \caption{A comparison of singlet and doublet lens spots.}
    \label{fig:chromatic}
\end{indentedfigure}
A downside to such a design is the increase in the number of lens elements used. To reduce the aberration, lower index lenses are needed to correct spherical and astigmatic, and chromatic aberrations; if corrections for spherical, astigmatic, and chromatic aberrations must be done, additional lens elements are needed. Additionally, the most desirable glasses for color correction often have properties that make them more expensive and difficult to manufacture. Minimising chromatic aberration by using monochromatic light has considerable savings in cost and complexity.
\nl
\subsubsection{Chromatic Focal Shift}
\textbf{Chromatic Focal Shift} is a type of chromatic aberration, chromatic focal shift describes how different wavelengths focus along different longitudinal positions (along the optical axis). The goal of most imaging lens designs is to have all desired wavelengths focus on the same plane (where the sensor is located). It is physically impossible to get a singular focus plane over a wide spectral range. However, it is possible to come close. If the wavelengths are focused closer to the same plane, fewer issues will be observed in the image.
\begin{indentedfigure}
    \centering
    
    \caption{Chromatic focal shift curve for an achromatic lens.}
    \label{fig:achromat}
\end{indentedfigure}
\ref{fig:achromat} shows a chromatic focal shift curve. Since this is an example of an achromatic lens design, two wavelengths are focused on the same plane. The y-axis shows changing wavelength from short to long (blue to red in the visible spectrum). The vertical black line represents a plane that could be the sensor location, and the x-axis shows the distance away from that location. The blue curved line shows the relative location of the best focus as a function of wavelength. The curve verifies that this design is achromatic since even if moved slightly to the left or right, the black line intersects the blue curve at only two points/wavelengths.
The blue, green, and red dots represent wavelengths associated with common 470nm, 520nm, and 630nm (blue, green, and red) LEDs. Notice the green dot focuses to the left of the sensor plane, while the red and blue dots focus to the right; this is the most balanced position of focus of the lens system if all the wavelengths or white light (which encompasses all wavelengths) are used. This design displays non-ideal image quality, as none of the wavelengths are truly in focus. If only one wavelength is used, the performance will improve since balancing effects used for the other wavelengths are eliminated. While this example demonstrates that red and blue can be balanced, this is not always true. Most lens designs are achromatic, but for very small pixels, this can be an issue.
\begin{indentedfigure}
    \centering
    
    \caption{Chromatic focal shift for an apochromatic lens.}
    \label{fig:apochromat}
\end{indentedfigure}
Shown at the same scale as \ref{fig:achromat}, \ref{fig:apochromat} shows an apochromatic lens. An apochromatic lens is designed to focus three wavelengths on the same plane. While this is a far more complicated design, it allows for superior balancing across the wavelength spectrum. As shown, all three LED colors can be brought to focus on the same sensor plane allowing for superior image quality. Apochromatic lens designs have high performance, but low versatility and work well over a smaller range of magnifications and WDs. Additionally, these are often high-cost designs due to additional elements made of expensive materials. Many high-end, high-magnification objectives (such as microscope objectives) are apochromatic.

\subsection{Filter types}
\subsubsection{IR-cut filters}
Generally, systems such as CMOS and CCD cameras capture accurate images in daylight. Their sensors can detect near-infrared light that is invisible to the human eye. Whilst this can be an important feature for night-vision recording, the infrared light distorts the colours of recorded images during daytime hours.
\\
\textbf{Infrared (IR) cut filters} are a mechanical shutter design that blocks or delivers the IR, providing a high quality image with true colour reproduction, irrespective of day or night. To make images more similar to waht humans can view, most OEM cameras are fitted with an IR-cut filter which allows only the visible light to pass through, thereby reflecting the unwanted IR.
\begin{indentedfigure}
    \centering
    
    \caption{Comparison of images with and without IR-cut filter.}
    \label{fig:IR-cut}
\end{indentedfigure}
\begin{indentedfigure}
    \centering
    
    \caption{Placement of IR-cut filter in a camera}
    \label{fig:IR-cut-diagram}
\end{indentedfigure}
The filter is controlled by a motor or with the help of an electromagnet. When the IR filter is turned on during daytime, it helps to block IR, letting only the visible light pass through. This process is known as \textbf{True Day Night (TDN)} because it delivers true colour images during the day and black and white or night vision images at night. It ensures that the image colours are not disturbed and generates a true representation of colours, as seen by naturally by the human eye.
When the IR filter is turned off during the night or in low-light confitions, it helps IR and other forms of light to reach the CCD/CMOS sensor. The image sensor, in turn, absorbs enough light, and the camera turns back to black-and-white mode, which is more sensitive to IR light.
\nl
There are three main reasons to use an IR-cut filter:
\begin{itemize}
    \item \textbf{To avoid colour distortion}. Generally, IR light leads to colour distortion during the day. To solve this issue, an IR-cut filter is used to keep the IR light disturbance out of the image sensor during the day. When the light falls below a certain level, the filter automatically swivels out of the way so that the IR light does hit the image sensor. Also, the camera switches to black-and-white mode to use the IR light optically.
    \item \textbf{To achieve realistic colours}. The IR-cut filter in a colour camera can achieve realistic colours in white light. In general, the colour spectrum viewed by the human eye is quite limited compared to the sepctrum viewed by a CCD camera. Especially, the difference in sensitivity is significant in the near IR region of the spectrum. If an IR-cut filter is not used, a huge amount of infrared light will appear, resultin in strange colours.
    \item \textbf{To achieve colour correction in lenses}. In many cases, it is difficult to design imaging optics covering both the visible sepctrum and the near IR spectrum. Therefore, many lenses have different depths of focus for the visible and the IR spectrum. In such cases, the IR-cut filter cuts away a significant amount of the collected light and achieves colour correction in lenses.
\end{itemize}
\begin{indentedfigure}
    \centering
    
    \caption{Comparison of standard lens and IR-corrected lens}
    \label{fig:IR-day-night}
\end{indentedfigure}
\subsubsection{Bayer filters vs. monochrome sensors}
\textbf{Bayer filters} and \textbf{monochrome sensors} are distinct approaches to image capture in digital cameras. Bayer filters are used in standard colour cameras to capture colour information, while monochrome sensors capture only light intensity without colour information. This leads to differences in image quality, low-light performance, and resolution.
\nl
Bayer filters, also known as \textbf{Colour Filter Arrays (CFAs)} are used to create colour images. They consist of a mosaic of red, green and blue filters arranged over the sensor's pixels.
Each pixel in a Bayer sensor captures only one colour component. To create a full-colour image, the missing colour information for each pixel is interpolated from its neighbours, a process that can introduce some softness or artifacts.
Bayer filters are the standard for most digital cameras and camcorders.
\begin{indentedfigure}
    \centering
    
    \caption{Simple Bayer sequence of RGGB.}
    \label{fig:bayer-sequence}
\end{indentedfigure}
As shown in \ref{fig:bayer-sequence}, bayer filters use a RGGB sequence to emulate the vision of the human eye since we are more sensitive to green light compared to red and green.
Unfortunately, the colour filter array reduces the amount of light reaching the sensor, potentially impacting low-light performance. Interpolation can also slightly reduce sharpness compared to monochrome sensors.
Fortunately, they provide the ability to capture full colour information in a single shot.
\nl
Monochrome sensors only capture the intensity of light without any colour filtering. Because they capture all the light information at each pixel, monochrome sensors can provide higher resolution and finer detail compared to Bayer sensors, especially in low-light conditions.
Without the light-absorbing colour filters, monochrome sensors are more sensitive to light, making them better in low-light situations. They are favoured in scientific, industrial and specialised applicants where colour information is not essential.
Although they capture only greyscale images, monochrome sensors can also be used with filters to create different black and white looks. They also offer greater flexibility in post-processing for contrast and tone adjustments.
Since there is no need for colour interpolation, monochrome sensors can offer sharper images with more detail.

\subsubsection{Bandpass \& ND filters}
\textbf{Bandpass} and \textbf{Neatural Density (ND)} filters are crucial in imaging missions for enhancing image quality, controlling light, and enabling specific observations. Bandpass filters isolate specific wavelengths of light, improving contrast and clarity, while ND filters reduce overall light intensity, preventing sensor saturation in bright conditions and allowing for longer exposure times.
\nl
Bandpass filters selectively transmit a specific range of wavelengths while blocking others, which is useful for isolating specific features or phenomena in an image. Some of the applications include:
\begin{itemize}
    \item \textbf{Astronomy}. Enhancing contrast in images of nebulae and galaxies by isolating specific emission lines.
    \item \textbf{Fluroescence microscopy}. Isolating excitation and emission wavelengths to visualise specific biological molecules.
    \item \textbf{Machine vision}. Improving contrast and resolution by reducing chromatic aberration and selecting relevant wavelengths.
    \item \textbf{Environmental monitoring}. Detecting specific gases or pollutants based on their spectral signatures.
    \item \textbf{Remote sensing}. Identifying materials and vegetation based on their unique spectral reflectance.
\end{itemize}
Some of the benefits include:
\begin{itemize}
    \item \textbf{Improved Signal-to-Noise (SNR) ratio}. By blocking unwanted light, bandpass filters enhance visibility of the desired signal.
    \item \textbf{Enhanced contrast and clarity}. Isolating specific wavelengths allows for clearer visualisation of target features.
    \item \textbf{Precise spectral analysis}. Bandpass filters are essential for spectroscopic analysis and identifying chemical compositions.
\end{itemize}

ND filters reduce the intensity of all wavelengths of light equally, allowing for slower shutter speeds or wider apertures in bright conditions. Some of the applications include:
\begin{itemize}
    \item \textbf{Daytime photography and videography}. Preventing overexposure in bright sunlight and enabling creative effects like motion blur.
    \item \textbf{Long-exposure photography}. Allowing for long exposures in daylight to capture light trails or smooth water.
    \item \textbf{Drone imaging}. Controlling exposure in aerial photography and videography.
\end{itemize}
Some of the benefits include:
\begin{itemize}
    \item \textbf{Controlled exposure}. ND filters allow for proper exposure in bright conditions, preventing sensor saturation.
    \item \textbf{Creative effects}. Enabling long exposures and motion blur in bright environments.
    \item \textbf{Sensor protection}. Reducing light intensity can help protect the sensor from damage in very bright conditions.
\end{itemize}

In some imaging missions, bandpass and ND filters are used together. For example, in drone imaging, a bandpass filter might be used to isolate secific spectral band for vegetation analysis, while an ND filter could be used to control the overall exposure level.
Dual bandpass filters can be used to optimise imaigng for both visible and near-IR light.

% -----------------------
% WEEK 2
% -----------------------

\section{Image Sensors \& Signal Conversion}
\subsection{Photodiodes}
Photodiodes are semiconductor devices that convert light into electrical current. When light, specifically photons, strike the photodiode's p-n junction, they generate electron-hole pairs. These carriers are then separated by the electric field in the depletion region, creating a photocurrent. The amount of current produced is directly related to the intensity of the incident light. 
\begin{indentedfigure}
    \centering
    
    \caption{Photodiode diagram}
\end{indentedfigure}
Photodiodes can operate in two main modes:
\\
\textbf{Photovoltaic mode}. In this mode, no external voltage is applied, and the photodiode generates a voltage when exposed to light.
\\
\textbf{Photoconductive mode}. A reverse bias voltage is applied, increasing the depletion region and enhancing the photodiode's sensitivity and response speed.

\subsubsection{Photoelectric effect}
The photoelectric effect is the emission of electrons from a material caused by electromagnetic radiation such as ultraviolet light. Electrons emitted in this manner are called photoelectrons. The phenomenon is studied in condensed matter physics, solid state, and quantum chemistry to draw inferences about the properties of atoms, molecules and solids. The effect has found use in electronic devices specialised for light detection and precisely timed electron emission.
\nl
The photoelectric effect is the core principle of how digital cameras operate. When a photon strikes the photodiode, it transfers energy to electrons in the material (typically silicon). This is a direct application of the photoelectric effect. These freed electrons are collected and stored as an electric charge in a potential well. The more photons hit the pixel, the more electrons accumulate, this is how brightness is measured. The camera's electronics read out the stored charges and convert them to digital values, which are processed to form the final image.

\subsubsection{Quantum efficiency}
\textbf{Quantum efficiency (QE)} in camera sensors refers to the percentage of incoming photons that are successfully converted into electrons, which are then used to form an image. A higher QE indicates a more efficient sensor, meaning it can produce a stronger signal from the same amount of light, leading to better image quality, particularly in low-light conditions. 
\nl
QE is a crucial factor in determining a camera's sensitivity, especially in low-light situations. Higher QE leads to better signal-to-noise ratio, meaning a clearer, less noisy image, especially when light levels are low.
QE varies with the wavelength of light. Some sensors are more efficient at certain wavelengths than others. Different sensor technologies (e.g., CCD, CMOS, back-illuminated, front-illuminated) have varying QE characteristics. Back-illuminated sensors generally have higher QE than front-illuminated sensors, but they are also more expensive. 

\subsubsection{Charge accumulation}
In camera sensors, \textbf{charge accumulation} is the process where light is converted into electrical charge within tiny light-sensitive elements called pixels. This charge is accumulated proportionally to the intensity of the light striking each pixel during the exposure time. The accumulated charge is then read out and processed to create the final image. 
\nl
In \textbf{Charge-Coupled Device (CCD)} sensors, the accumulated charge is transferred through the sensor's grid, like a bucket brigade, to a common readout circuit. 
In \textbf{Complementary Metal-Oxide-Semiconductor (CMOS)} sensors, the charge at each pixel is converted to a voltage, and then the signal is read out. 
The accumulated charge values from all pixels are then read out, converted into digital data, and processed by the camera's electronics to form the final image. 

\subsubsection{Full well}
A \textbf{full well} in an image sensor is the amount of charge that can be stored within an individual pixel without the pixel becoming saturated. It is dependent on the pixel size of the sensor and the camera operating voltages.
\begin{indentedfigure}
    \centering
    
    \caption{Three different cameras with 2.5, 5 and 10 µm pixels. The full well capacity increases with increasing pixel size.}
\end{indentedfigure}
Different sized pixels are used for different applications. Whilst a smaller pixel size increases the number of pixels that can be placed on a sensor, the number of photons each pixel can detect is also reduced for the same photon flux, and therefore quantum efficiency tends to be reduced. Since fewer photons are collected the signal is lower and so the signal-to-noise ratio is reduced.
On the other hand, if the sensor is too big, or contains too many pixels, a much greater computational power is required to process the output information, decreasing image acquisition. It is important to select a camera sensor that balances the pixel size requirements with the acceptable noise levels for the application.
Generally, larger pixel sizes are used for achieving a higher sensitivity whilst smaller pixels are used for obtaining a higher spatial resolution.
\nl
Below is a diagram of a general pixel - not specific to any sensor type. Please refer to this figure for concepts discussed later such as microlenses.
\begin{indentedfigure}
    \centering
    
    \caption{See caption above.}
\end{indentedfigure}

\subsubsection{Saturation}
At the saturation point, pixels are unable to store additional charges, so instead this charge is spread into neighboring pixels. This causes saturation within neighboring pixels also. This spread of charge is called blooming and is visualized as a white vertical streak or smear on the image. During readout, the excess electrons from the saturated signal are moved down the sensor, resulting in a vertical smear.

\subsubsection{Signal to Noise Ratio}
The \textbf{Signal to Noise Ratio (SNR)} of a camera describes the ratio between the light signal and the image noise.
\\
The perfect camera sensor would convert a known amount of light into a precisely predictable output voltage. Unfortunately, this perfect sensor does not exist in reality. Due to temperature conditions, electronic interference or similar, sensors do not convert light with 100\% accuracy.
Sometimes the output voltage is slightly higher than expected and sometimes slightly lower. The difference between the expected ideal signal and the signal actually received is referred to as noise.
\nl
The signal-to-noise ratio is usually specified as a factor, for example: 20:1, 30:1, etc. Alternatively, the signal-to-noise ratio can also be expressed in decibels (dB).
The formula for calculating the signal-to-noise ratio in dB is: $\texttt{SNR} = 20* \log (\texttt{signal}/\texttt{noise})$.
\begin{indentedfigure}
    \centering
    
    \caption{The signal-to-noise ratio: from low (left) to high (right) signal-to-noise ratio.}
\end{indentedfigure}
Once noise has become part of a signal, it can no longer be filtered or reduced. It is therefore advisable to take precautions to reduce the generation of noise, such as:
\begin{itemize}
    \item Use high-quality sensors and electronic devices in your camera.
    \item Use a good electronic architecture in the development of your camera.
    \item Lower the temperature of the sensor and other analog devices in your camera.
    \item Shield against interfering environmental conditions that affect the signal (e.g. by using shielded cables).
\end{itemize}
Camera users often increase the gain setting of their camera thinking that they are improving the signal-to-noise ratio. Since increasing the gain increases both the signal and the noise, the signal-to-noise ratio does not change significantly when the gain is increased. Gain is not an effective means of increasing the information content of the signal. Gain only changes the contrast of an existing image.

\subsection{Sensors}
\subsubsection{CCD}
A \textbf{charge-coupled device (CCD)} is an integrated circuit containing an array of linked, or coupled, capacitors. Under the control of an external circuit, each capacitor can transfer its electric charge to a neighbouring capacitor. CD sensors are a major technology used in digital imaging.
\begin{indentedfigure}
    \centering
    
    \caption{Block Diagram of a Charge-Coupled Device (CCD).}
\end{indentedfigure}
In a CCD image sensor, pixels are represented by p-doped metal-oxide-semiconductor (MOS) capacitors. These MOS capacitors, the basic building blocks of a CCD, are biased above the threshold for inversion when image acquisition begins, allowing the conversoin of incoming photons into electron charges at the semiconductor-oxide interface; the CCD is then used to read out these charges.
Although they are not the only light-detection technology, they are widely used in applicaitons where high-quality image data are required.
\nl
In a CCD for capturing images, there is a photoactive region (an epitaxial layer of silicon), and a transmission region made out of a shift register (the CCD). An image is projected through a lens onto the capacitor array, causing each capacitor to accumulate an electric charge proportional to the light intensity at that location.
A one-dimensional array, used in line-scan cameras, captures a single slice of the image, whereas a two-dimensional array, used in video and still cameras, captures two dimensional picture corresponding to the scene projected onto the focal plane of the sensor.
Once the array has been exposed to the image, a conrol circuit causes each capacitor to transfer its contents to its neighbour (operating as a shift register). The last capacitor in the array dumps its charge into a charge amplifier, which converts the charge into a voltage.
By repeating this process, the controlling circuit converts the entire contents of the array  in the semiconductor to a sequence of voltages. In a digital device, these voltages are then sampled, digitised, and usually stored in memory; in an analog device, they are processed into a continuous analog signal, which is then processed and fed out to other circuits for transmission, recording, or other processing.

\subsubsection{CMOS}
\textbf{Complementary metal-oxide-semiconductor (CMOS)} is an image sensor with an amplifier for each pixel, compared to the few amplifiers of a CCD. This results in less area for the capture of photons that a CCD, but this problem has been overcome by using microlenses in front of each photodiode, which focus light into the photodiode that would have otherwise hit the amplifier and not been detected. Some CMOS imaging sensors also used Back-side illumination to increase the umber of photons that hit the photodiode.
CMOS sensors can potentially be implemented with fewer components, use less power, and/or provide faster readout than CCD sensors. They are also less vulnerable to static electricity discharges.
\begin{indentedfigure}
    \centering
    
    \caption{Block Diagram of a Complementary Metal Oxide Semiconductor (CMOS).}
\end{indentedfigure}
\subsubsection{Performance}
There are many parameters that can be used to evaluate the performance of an image sensor, including dynamic range, SNR, and low-light sensitivity. For sensors of comparable types, the SNR and dynamic range improve as the size increases because in a given exposure time, more photons hit the pixel with larger area.

\subsubsection{Architecture}
CCDs converts incoming photos into electrons, which are then shifted across the sensor, pixel by pixel, to an output amplifier. The signal from each pixel is read out sequentially, one after another, leading to a slower readout process. CCDs traditionally offer higher sensitivity and lower noise due to the charge transfer process, amking them suitable for low-light conditions and scientific applications. Despite this, they generally consume more power and are most costly compared to CMOS sensors.
\nl
In CMOS sensors, each pixel has its own amplifier and other circuitry, allowing for simultaneous readout of all pixels. The parallel readout enables much faster image capture compared to CCDs. They are typically cheaper and require less power to operate.
The presence of amplifiers and other circuitry can introduce more noise compared to CCDs.

\subsubsection{Shutter}
CCD sensors primarily use a global shutter, exposing the entire sensor at once, while CMOS sensors typically employ a rolling shutter, exposing the sensor line by line.
\nl
The image from a CCD can result in more accurate representations of a single moment in time, minimising artifacts. If there's motion within the scene during the exposure, the global shutter can lead to a blurred image if the shutter speed is not fast enough to freeze the action.
In bright conditions, CCDs can be susceptible to vertical smear, where bright light overloads the sensor and spills into adjacent pixels.
\nl
CMOS sensors typically expose the image line by line, creating a scan-like effect. This can lead to various motion artifacts like skew, wobble, and partial exposure.
CMOS sensors generally handle bright light better than CCDs and are less prone to blooming and smearing. In situations with flickering light sources, CMOS sensors may exhibit a rolling dark bar across the image.

\subsubsection{Overall Advantages vs. Disadvantages}
\textbf{CMOS - Advantages}:
\begin{itemize}
    \item \textbf{Lower power consumption}: Ideal for battery-powered devices.
    \item \textbf{Faster readout speeds}: CMOS sensors can capture and process images more quickly.
    \item \textbf{Lower manufacturing costs}: The simpler design and mass production capabilities of CMOS sensors make them cheaper to produce.
    \item \textbf{Greater flexibility and functionality}: They can be integrated with other features on the same chip, leading to more versatile and compact devices.
\end{itemize}
\textbf{CMOS - Disadvantages}:
\begin{itemize}
    \item \textbf{Higher noise levels}: The presence of amplifiers and ADCs at each piel can introduce more noise.
\end{itemize}

\textbf{CCD - Advantages}:
\begin{itemize}
    \item \textbf{Higher image quality in some applications}: CCD sensors were historically known for their ability to capture images with lower noise and better dynamic range, especially in scientific and astronomical imaging.
    \item \textbf{Softer, less digital-looking images}: Some users find the image rendering of CCD sensors to be more pleasing aesthetically, with a softer sharpness.
    \item \textbf{Low light sensitivity}: CCDs were known for good performance in low-light conditions.
\end{itemize}
\textbf{CCD - Disadvantages}:
\begin{itemize}
    \item \textbf{Slower readout speeds}: The sequential nature of signal transfer in CCDs can make them slower.
    \item \textbf{Larger size and complexity}: CCDs tend to be larger and more complex than CMOS sensors.
\end{itemize}
CMOS sensors have largely taken over the mainstream camera market due to their lower power consumption, faster speeds, and lower cost. CCD sensors are still used in specialised applications where their superior image quality in certain scenarios is crucial. 

\subsection{Pixel Architecture}
\subsubsection{Microlens}
A \textbf{microlens} is a small lens, with diameter less than a millimetre and often as small as 10$\mu$m. The samll sizes of the lenses means that a simple design can give good optical quality but sometimes unwanted effects arise due to optical diffraction at the samll features. A typical microlens may be a single element with one plane surface and one spherical convex surface to refract the light.
Because microlenses are so small, the substrate that supports them is usually thicker than the lens and this has to be taken into account in the design.
\nl
A different type of microlens has two flat and parallel surfaces and the focusing action is obtained by a variation of refractive index across the lens. These are known as \textbf{gradient-index (GRIN) lenses}. Some micro-lenses achieve their focusing action by both a variation in refractive index and by the surface shape.
\nl
Another class of microlens, sometimes known as \textbf{micro-Fresnel lenses}, focus light by refraction in a set of concentric curved surfaces. Such lenses can be made very thin and lightweight. Binary-optic micro-lenses focus light by diffraction. They have grooves with stepped edges or multilevels that approximate the ideal shape. They have advantages in fabrication and replication by using standard semiconductor processes such as photolithography and reactive-ion etching (RIE).
\nl
Single micro-lenses are used to couple light to optical fibres; microlens arrays are often used to increase the light collection efficiency of CCD arrays and CMOS sensors, to collect and focus light that would have otherwise fallen onto the non-sensitive areas of the sensor.
\nl
With optical sensor arrays, tiny lens systems serve to focus and concentrate the light onto the photo-diode surface, instead of allowing it to fall on non-photosensitive areas of the pixel device. Fill-factor is the ratio of the active refracting area, i.e. that area which directs light to the photo-sensor, to the total contiguous area occupied by the microlens array.

\subsubsection{Pixel Binning}
Pixel binning is a technique used in digital imaging where multiple adjacent pixels on a camera sensors are combined into a single, larger \textit{super pixel}. This process increases the SNR, especially in low-light conditions, by gathering more light photons to each super pixel. However, it reduces the resolution of the image since the number of pixels is decreased.
For example, a 2x2 binning operation combines the charge from four pixels into one.

\subsubsection{Back-side Illumination}
A \textbf{back-illuminated (BI) sensor},  also known as \textbf{back-side illumination (BSI)} sensor, is a type of digital image sensor that uses a novel arrangement of the imaging elements to increase the amount of light captured and thereby improve low-light performance.
\nl
The technique was used for some time in specialized roles like low-light security cameras and astronomy sensors, but was complex to build and required further refinement to become widely used. Sony was the first to reduce these problems and their costs sufficiently to introduce a 5-megapixel 1.75$\mu$m BI CMOS sensor at general consumer prices in 2009.
BI sensors from OmniVision Technologies have since been used in consumer electronics from other manufacturers as in the HTC EVO 4G Android smartphone, and as a major selling point for the camera in Apple's iPhone 4.
\begin{indentedfigure}
    \centering
    
    \caption{Comparison of simplified back-illuminated and front-illuminated pixel cross-sections.}
\end{indentedfigure}
A traditional, front-illuminated digital camera is constructed in a fashion similar to the human eye, with a lens at the front and photodetectors at the back. This traditional orientation of the sensor places the active matrix of the digital camera image sensor, a matrix of individual picture elements, on its front surface and simplifies manufacturing. The matrix and its wiring, however, block some of the light, and thus the photocathode layer can only receive the remainder of the incoming light; the blockages reduces the signal that is available to be captured.
\nl
A back-illuminated sensor contains the same elements, but arranges the wiring behind the photocathode layer by flipping the silicon wafer during manufacturing and then thinning its reverse side so that light can strike the photocathode layer without passing through the wiring layer.
This change can improve the chance of an input photon being captured from about 60\% to over 90\%, with the greatest difference realised when pixel size is small, as the light capture area gained in moving the wiring from the top (light incident) is proportionately larger for a smaller pixel.

\subsubsection{Resolution vs sensitivity trade-off}
The resolution vs sensitivity trade-off in CubeSat cameras is a fundamental optical and sensor design challenge.
\\
Resolution is the level of detail a camera can capture. High resolution cameras use small pixels to fit more into an image. This increases the ability to distinguish small features.
\\
Sensitivity is the ability to capture light. Low-light cameras, e.g., Sony A7S3, use larger pixels to capture more photons, increasing the SNR.
\\
Since CubeSats have limited size for optics, restricted power and thermal budgets, and sometimes have extreme lighting conditions, it is important to find a balance between the two features.
Earth observation may prioritise resolution using higher quality optics and short exposure times (but may not work well on the dark side of Earth), whereas star tracking or imaging surfaces on the dark side of Earth would be better suited for a sensitive camera with slightly longer exposure times.
\nl
To find a balance between the two and optimise the system, we can:
\begin{itemize}
    \item Use binning in dark areas to increase sensitivity when needed.
    \item Employ active exposure control or HDR techniques.
    \item Choose a sensor with back-illumination for better quantum efficiency.
    \item Use adaptive optics or onboard image enhancement.
\end{itemize}

\subsection{Analog Signal Processing}
\subsubsection{Signal Chain}
The camera sensor signal chain is a series of steps that convert photons into a digital image. It begins with the image sensor, where light is converted into an electrical signal, then amplified, filtered, and digitized before being processed and stored.
\begin{indentedfigure}
    \centering
    
    \caption{Block diagram of camera sensor signal chain.}
\end{indentedfigure}
\begin{enumerate}
    \item \textbf{Image Sensor}: Light captured by the lens is focused on the image sensor, which contains millions of photodiodes.
    \item \textbf{Charge Conversion}: When light strikes a pixel, it generates a small electrical charge proportional to the light's intensity.
    \item \textbf{Signal Amplification}: The weak electrical signal from each pixel is amplified to improve its strength and signal-to-noise ratio.
    \item \textbf{Filtering}: Filters are used to remove unwanted noise and signals outside the desired frequency range. 
    \item \textbf{Analog-to-Digital Conversion (ADC)}: The amplified and filtered analog signal is converted into a digital signal by an ADC. This process samples the signal and assigns a digital value to each sample.
    \item \textbf{Image Processing}: The digital data then goes through further processing, including demosaicing (calculating the missing color information for each pixel), white balancing, sharpening, and noise reduction.
    \item \textbf{Storage}: Finally, the processed image data is stored on a memory card or transmitted to another device. 
\end{enumerate}
Different camera technologies, like CCD and CMOS sensors, have slightly different signal processing paths, but the core steps remain the same. For example, CCD sensors often require a more analog signal processing chain, while CMOS sensors have more integrated digital processing capabilities. 

\subsubsection{Noise Types}
In image sensors, common noise types include shot noise, read noise, and dark current noise. Shot noise arises from the statistical nature of photon detection, while read noise is introduced during the signal readout process. Dark current noise is caused by thermally generated electrons in the absence of light. These noise sources can significantly impact image quality, especially in low-light conditions or with long exposures. 
\nl
\textbf{Shot noise}, also known as photon noise, is a fundamental noise source caused by the inherent randomness in the arrival of photons at the image sensor.
Photons, being discrete particles, don't arrive at a perfectly uniform rate, leading to fluctuations in the number of detected electrons.  Shot noise is signal-dependent, meaning it increases with the strength of the incoming light signal. 
In high-light conditions, shot noise becomes the dominant noise source, while in low-light conditions, other noise sources might be more significant. 
\nl
\textbf{Read noise}, is introduced during the process of converting the electrical signal from the sensor into a digital value. It originates from the electronic components within the camera, such as amplifiers and analog-to-digital converters.
Read noise is generally independent of the signal level and sensor temperature. Read noise is often the dominant noise source in low-light or short-exposure images.
\nl
\textbf{Dark current noise}  is a small electrical current that flows in a sensor even when no light is detected. It is primarily caused by thermal generation of electrons within the sensor material.
Dark current increases with temperature and exposure time. Dark current noise can be a significant issue in long-exposure images or when using high-sensitivity sensors. 
\nl
\textbf{Fixed pattern noise (FPN)} is a type of noise in digital imaging sensors characterised by a consistent, repeating pattern across the image. It arises from manufacturing variations in the sensor, leading to some pixels having slightly different responses than others, regardless of the scene being captured. This pattern remains the same in each image, making it distinct from random noise. FPN is often more noticeable in low-light or long-exposure images. 
\nl
\textbf{Quantisation noise} is the error introduced when a continuous analog signal is converted into a discrete digital signal. This happens because the digital system can only represent a finite number of levels, so the original signal is rounded to the nearest available level. This rounding process creates a difference between the original and the quantized signal, which is perceived as noise. 
\nl
\textbf{Thermal or Johnson-Nyquist noise} , is the random voltage or current noise generated by the thermal agitation of charge carriers (like electrons) within electrical conductors at equilibrium, regardless of any applied voltage. It's a fundamental noise source present in all electrical circuits and is proportional to the absolute temperature. This noise can limit the sensitivity of sensitive electronic equipment, such as radio receivers, and is particularly noticeable at low signal levels. 
\nl
For a slightly more in-depth explanation of the different noise types, this \href{https://www.thorlabs.com/newgrouppage9.cfm?objectgroup_id=10773}{source} dives into more detail. In cameras, noise reduces the SNR, which makes it harder to detect real features in an image. This is especially problematic in low-light conditions, where the signal is weak and noise may dominate.
High noise floors limit the minimum detectable signal. It also compresses the dynamic range, making it harder to distinguish between bright and dark regions in a scene.
Noise characteristics will influence the choice of  the sensor and pixel size, gain settings, ADC resolution, and the need for cooling, shielfing, or post-processing corrections (like dark frame subtraction and/or denoising).

\subsection{Sensor Control Interfaces}
\label{sec:sony-imx}
Here, we will investigate the basics of the \textbf{Sony IMX219PQH5-C} image sensor, found \href{https://www.opensourceinstruments.com/Electronics/Data/IMX219PQ.pdf}{here}.
\nl
\subsubsection{Overview}
The IMX219PQH5-C is a diagonal 4.60 mm (Type 1/4.0) CMOS active pixel type image sensor with a square pixel array and 8.08M effective pixels. This chip operates with three power supplies, analogue 2.8 V, digital 1.2 V, and IF 1.8 V, and has low power consumption. High sensitivity, low dark current, and no smear are achieved through the adoption of R, G, and B primary color pigment mosaic filters. This chip features an electronic shutter with variable charge-storage time.
\begin{indentedfigure}
    \centering
    
    \caption{Overview of functional block diagram.}
\end{indentedfigure}

\subsubsection{Features}
\begin{itemize}
    \item Back-illuminated CMOS image sensor (Exmor R\texttrademark)
    \item On-chip 2-wire serial communication interface
    \item MIPI CSI-2 data output (2 or 4 lanes selectable)
    \item Integrated timing generator and horizontal/vertical driver circuits
    \item On-chip CDS (Correlated Double Sampling) and PGA (Programmable Gain Amplifier)
    \item 10-bit on-chip A/D conversion
    \item On-chip automatic optical black (OB) clamp circuit
    \item On-chip PLL (rectangular wave)
    \item High sensitivity, low dark current, no smear
    \item Strong anti-blooming performance
    \item Variable-speed shutter (1 H step)
    \item RGB primary color pigment mosaic filter
    \item Max 30 fps in full-resolution (all-pixel scan) mode
    \item Pixel rate: 280 Mpixel/s in all-pixels mode
    \item High-speed modes: 
        \begin{itemize}
        \item 180 fps @720p with 2*2 analog binning
        \item 60 fps @1080p with vertical cropping
        \end{itemize}
    \item Data rate: up to 755 Mbps/lane (4-lane), 912 Mbps/lane (2-lane)
\end{itemize}

\subsubsection{Communication Protocol}
This sensor uses the 2-wire serial communication method for sensor control. These specifications are described for sensor control using the 2-wire serial communication as follows.
\begin{indentedfigure}
    \centering
    
    \caption{2-wire serial communication.}
\end{indentedfigure}
The 2-wire serial communication method conforms to the Camera Control Instance (CCI). CCI is an I$^2$C fast-mode compatible interface, and the data transfer protocol is the I$^2$C standard. This 2-wire serial communication circuit can be used to access the control registers and status-registers of this sensor.
\nl
2-wire serial communication supports a 16-bit register address and 8-bit data message type.
\begin{indentedfigure}
    \centering
    
    \caption{2-wire serial communication protocol.}
\end{indentedfigure}

\subsubsection{Register Control}
Naturally, all the register controls cannot be listed on a single page since most drivers for these types of image sensors are thousands of lines long. For simplicity, we will cover a few examples of setting up the registers for a specific purpose.
\nl
\textbf{Analog gain} on the sensor can be set using the following equation:
\[
G=\frac{m0\times X+c0}{m1\times X + c1}
\]
The variables are shown in the table below.
\begin{indentedfigure}
    \centering
    
    \caption{Gain setting variables.}
\end{indentedfigure}
Therefore, the analogue gain is as follows:
\[
G = \frac{256}{256-X}
\]
Where $X$ can be controlled between 0-232 via the 0x0157 or 0x0257 register address.
\nl
The default \textbf{readout position} is from the lower left corner when Pin 1 is located in the upper right corner. The image is inverted vertically and horizontally by the lens, so proper output results when Pin 1 is located in the upper right corner.
\begin{indentedfigure}
    \centering
    
    \caption{Readout Position.}
\end{indentedfigure}
Readout direction can be set by the registers:
\begin{indentedfigure}
    \centering
    
    \caption{Image Orientation Register.}
\end{indentedfigure}
\begin{indentedfigure}
    \centering
    
    \caption{Output Image Diagrams for Vertical Flip and Horizontal Mirror.}
\end{indentedfigure}

The \textbf{temperature sensor} measures the junction temperature of the silicon sensor. The target range is -10 to 95\textdegree C, with $\pm5$\textdegree in deviation. The sensor is operated immediately after streaming mode, and the value will be stored in the register.
\\
Registers to be related about temperature sensor are the followings:
\begin{indentedfigure}
    \centering
    
    \caption{Temperature setting registers.}
\end{indentedfigure}
The following table shows the relationship between temperature and stored value:
\begin{indentedfigure}
    \centering
    
    \caption{Temperature value relationship.}
\end{indentedfigure}

% -----------------------
% WEEK 3
% -----------------------

\section{Image Processing Pipeline}

\subsection{Demosaicing and Bayer pattern reconstruction}
\textbf{Demosaicing}, also known as colour reconstruction, is a digital image processing algorithms used to reconstruct a full colour image from the incomplete samples output from an image sensor averlaid with a colour filter array like a Bayer filter. It is also known as CFA interpolation or debayering.
\nl
Most modern digital cameras acquire images using a single image sensor overlaid with a CFA, so demosaicing is part of the processing pipeline required to render these images into a viewable format. Many modern cameras can save images into a .RAW format, allowing the user to demosaic them using software, rather than using the camera's built-in firmware.
\nl
The aim of a demosaicing algorithm is to reconstruct a full colour image from the spatialy undersampled colour channels output from the CFA. The algorithm should have the following traits:
\begin{itemize}
    \item Avoidance of the introduction of false colour artifacts, such as chromatic aliases, zippering and purple fringing
    \item Maximum preservation of the image resolution
    \item Low computational complexity for fast processing or efficient in-camera hardware implementation
    \item Amenability to analysis for accurate noise reduction
\end{itemize}

\subsubsection{Bilinear vs edge-aware algorithms}
Bilinear and edge-aware demosaicing are two different approaches to reconstructing a full-colour image from a Bayer filter mosaic.
\nl
\textbf{Bilinear interpolation} is a simple, fast method that averages neighbouring pixel values to estimate missing colour components, but it often produces artifacts, especially around edges.
\nl
\textbf{Edge-aware algorithms}, on the other hand, are more sophisticated, taking into accound image edges and high-frequency details to produce a more accurate reconstruction.

\subsection{White Balance, Gamma, and Exposure Control}
\subsubsection{White Balance}
\textbf{White balance} is a camera setting that adjusts colours in an image to make white objects appear white, regardless of the colour temperature of the light source. It ensures photos are depicted accurately by compensating for the colour cast of different light sources light sunlight or artificial light.
While white balance specifically targets whites, white balance affects all colours in the image because it adjusts the overally colour temperature.
\nl
Colour temperature is measured in Kelvin (K) and describes the relative warmth or coolness of white light. Lower temperatures (e.g., 2700K) represent warmer, reddish-yellow light (like incandescent bulbs).
Higher temperatures represent cooler, bluish light (like fluorescent lights).
\nl
Whilst you can acheive white balance in post-processing, it's often best to get it as close as possible in-camera for the best results, especially when shooting in .RAW format.
\nl
Depending on the orbit or target, we may face different lighting conditions (e.g., reflected sunlight, albedo changes) that will impact the image. If the white balance is not correct and we do not shoot in .RAW, the colour data is most likely unrecoverable. Many sensors like the IMX477 include auto-WB; but for scientific data, manual tuning or calibrated WB is often better.
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

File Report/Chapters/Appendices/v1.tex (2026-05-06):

\subsection{Pin Justification Tables}

% ------------------------
% STM32U575RI 144-Pin Justification Tables
% ------------------------

\begin{table}[H]
    \centering
    \begin{tabular}{|l|p{3cm}|p{6cm}|p{4.5cm}|}
        \hline
        \textbf{Pin} & \textbf{Function} & \textbf{Reason} & \textbf{Requirements} \\
        \hline
        1 & VBAT & Backup power supply for RTC and backup registers & nil. \\ \hline
        2 & SHUTTER & Close to camera module trigger interface & Requires an external interrupt pin \\ \hline
        3 & RCC\_OSC32\_IN & Input for the low-speed external 32.768 kHz crystal & 32.768kHz \\ \hline
        4 & LED\_MCU & Status indicator for MCU operation & GPIO \\ \hline
        5 & RCC\_OSC\_IN & Input for the high-speed external oscillator & 4-50MHz \\ \hline
        6 & LED\_ERR & Error status indicator & GPIO \\ \hline
        7 & NRST & System reset pin (active low) & nil. \\ \hline
        8 & OCTOSPIM\_P1\_IO7 & Auto assigned by STM32CubeIDE after selecting 'PORT1 IO[7:4]' on Data [3:0] \hypertarget{octo-io-8}{[1]} & nil. \\ \hline
        9 & OCTOSPIM\_P1\_IO4 & \hyperlink{octo-io-8}{1} & nil. \\ \hline
        10 & OCTOSPIM\_P1\_IO5 & \hyperlink{octo-io-8}{1} & nil. \\ \hline
        11 & OCTOSPIM\_P1\_IO6 & \hyperlink{octo-io-8}{1} & nil. \\ \hline
        12 & VSSA & Analog ground reference & Tie to VSS/GND \\ \hline
        13 & VDDA & Analog power supply & 1.62-3.6V \\ \hline
        14 & PA0 & nil. & nil. \\ \hline
        15 & SPI1\_SCK & Auto assigned by STM32CubeIDE after selecting 'Full-Duplex Master' on Mode & nil. \\ \hline
        16 & OCTOSPIM\_P1\_NCS & Auto assigned by STM32CubeIDE after selecting 'Port1 NCS' on 'Chip Select' & nil. \\ \hline
        17 & OCTOSPIM\_P1\_CLK & Auto assigned by STM32CubeIDE after selecting 'Port1 CLK' on Clock & nil. \\ \hline
        18 & VSS & Digital ground & nil. \\ \hline
        19 & VDD & Digital power supply & 1.71-3.6V \\ \hline
        20 & DCMI\_HSYNC & Auto assigned by STM32CubeIDE after selecting 'Slave 12 bits' on DCMI \hypertarget{dcmi-reason}{[2]} & nil. \\ \hline
        21 & DCMI\_GPIO0 & General purpose control for camera sensor & GPIO \\ \hline
        22 & DCMI\_PIXCLK & \hyperlink{dcmi-reason}{2} & nil. \\ \hline
        23 & SPI1\_MOSI & Auto assigned by STM32CubeIDE after selecting 'Full-Duplex Master' on Mode & nil. \\ \hline
        24 & DCMI\_GPIO1 & General purpose control for camera sensor & GPIO \\ \hline
        25 & DCMI\_GPIO2 & General purpose control for camera sensor & GPIO \\ \hline
        26 & DCMI\_GPIO3 & General purpose control for camera sensor & GPIO \\ \hline
        27 & PB1 & nil. & nil. \\ \hline
        28 & PB2 & nil. & nil. \\ \hline
        29 & I2C2\_SCL & Auto assigned by STM32CubeIDE after selecting 'I2C2' & nil. \\ \hline
        30 & VCAP & Internal regulator filtering & External capacitor required \\ \hline
    \end{tabular}
    \caption{Pin justification for STM32U575RITx (Pins 1-30).}
    \label{tab:stm32u575-pin-justification-1}
\end{table}
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

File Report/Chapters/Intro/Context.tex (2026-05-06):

The \textbf{CubeSat Camera System (C2S)} is the proposed mission payload for the Perth Aerospace Student Team's (PAST) first CubeSat. This inaugural mission represents a critical milestone in the team's broader goal of developing low-cost, modular spacecraft capable of performing meaningful scientific and engineering demonstrations in Low Earth Orbit (LEO). C2S is designed to operate as an Earth observation payload, taking photos of land- and ocean-scapes. Beyond its imaging objectives, the system will serve as a testbed for evaluating the viability of student-developed space hardware in a real orbital environment. The payload aims to balance performance, reliability, and resource constraints typical of CubeSat-class missions.
\nl
This document outlines the key design drivers, system architecture, component selection strategies, and trade-offs that inform the development of the CubeSat Camera System prototype. It also provides an overview of the integration challenges and planned validation strategies for the final model.
\nl
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

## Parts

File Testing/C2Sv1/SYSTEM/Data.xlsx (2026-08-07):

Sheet: SYS INFO
Item | Value | Units | Part Number | Notes
Shunt Resistor | 1.6 | Ohm | ERJ-6DQF1R6V
VSEL | 5 | V
VCC | 3.3 | V
LED Resistor | 470 | Ohm | CRCW0603470RFKEC
LED Forward Voltage | 1.79 | V | HSMH-H190 | Measured FV with multimeter
LDO Power Loss Ratio | 0.52 |  |  | Power loss is directly proportional to system power
System Power Ratio | 0.66 |  |  | How much the system actually uses in relation to LDO ratio
Measured voltages were exactly ideal values.

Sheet: Baselines
Current Sense Amplifier (Multimeter) |  |  | 3V3 LED (Multimeter) |  |  | System Power (CSA)
Test # | Shunt Voltage (mV) | Estimated System Power (mW) | Test # | Shunt Voltage (V) | Estimated LED Power (mW) | Test # | CSA Power (mW) [QSPI SLEEP] | Test # | CSA Power (mW) [QSPI ACTIVE]
1 | 49 | 101.1 | 1 | 1.517 | 10.65 | 1 | 151 | 1 | 149
2 | 48.9 | 100.9 | 2 | 1.517 | 10.65 | 2 | 150 | 2 | 152
3 | 48.7 | 100.4 | 3 | 1.517 | 10.65 | 3 | 150 | 3 | 150
4 | 48.7 | 100.4 | 4 | 1.517 | 10.65 | 4 | 149 | 4 | 149
5 | 49 | 101.1 | 5 | 1.518 | 10.66 | 5 | 149 | 5 | 152
 |  |  |  |  |  | 6 | 151 | 6 | 152
 | Average | 100.8 |  | Average | 10.65 | 7 | 151 | 7 | 149
 |  |  |  |  |  | 8 | 150 | 8 | 150
 |  |  |  |  |  | 9 | 152 | 9 | 152
 |  |  |  |  |  | 10 | 152 | 10 | 151
 |  |  |  |  |  | 11 | 152 | 11 | 150
 |  |  |  |  |  | 12 | 153 | 12 | 150
 |  |  |  |  |  | 13 | 150 | 13 | 149
 |  |  |  |  |  | 14 | 149 | 14 | 151
 |  |  |  |  |  | 15 | 149 | 15 | 151
 |  |  |  |  |  | 16 | 151 | 16 | 152
 |  |  |  |  |  | 17 | 153 | 17 | 149
 |  |  |  |  |  | 18 | 151 | 18 | 154
 |  |  |  |  |  | 19 | 151 | 19 | 152
 |  |  |  |  |  | 20 | 151 | 20 | 151
 |  |  |  |  |  | 21 | 148 | 21 | 151
 |  |  |  |  |  | 22 | 148 | 22 | 150
 |  |  |  |  |  | 23 | 152 | 23 | 152
 |  |  |  |  |  | 24 | 151 | 24 | 150
 |  |  |  |  |  | 25 | 148 | 25 | 149
 |  |  |  |  |  | Average | 150.5 | Average | 150.7
 |  |  |  |  |  | Virtually no difference between QSPI in active/sleep mode.
 |  |  |  |  |  | Makes sense as difference between the two is 40uA which is approx 130uW.
 |  |  |  |  |  | Cannot measure power during read/write as it is a blocking function
 |  |  |  |  |  | Can extrapolate from pg. 113 of datasheet
 |  |  |  |  |  | No need to apply system ratio here. The difference is so small that the ratio would not make an impact on the result

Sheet: Camera Test
QVGA Image |  |  |  | VGA Image |  |  |  | Image Capture |  | No Image Capture |  | Image Transfer |  | Power Summary
Time (ms) | System Power (mW) | Factored System Power (mW) |  | Time (ms) | System Power (mW) | Factored System Power (mW) |  |  | Average Power (mW) |  | Average Power (mW) |  | Average Power (mW) |  | Average Power (mW)
75 | 298 | 196.68 | CAMERA ON | 75 | 149 | 98.34 | CAMERA ON | QVGA | 149.2 | QVGA | 99.3 | QVGA | 158.1 | System | 98.0
150 | 220 | 145.2 |  | 150 | 217 | 143.22 |  | VGA | 151.4 | VGA | 96.8 | VGA | 106.6 | Camera | 52.3
225 | 220 | 145.2 |  | 225 | 218 | 143.88 |  | Difference | 2.2 | Difference | 2.5 | Difference | 51.6 | USB | 34.3
300 | 219 | 144.54 |  | 300 | 221 | 145.86
375 | 220 | 145.2 |  | 375 | 222 | 146.52
450 | 223 | 147.18 |  | 450 | 220 | 145.2 |  |  |  | No apparent difference in power consumption between VGA and QVGA outside of runtime as power difference within one magnitude of uncertainty
525 | 222 | 146.52 |  | 525 | 225 | 148.5
600 | 223 | 147.18 |  | 600 | 223 | 147.18
675 | 222 | 146.52 |  | 675 | 218 | 143.88
750 | 227 | 149.82 |  | 750 | 219 | 144.54
825 | 223 | 147.18 |  | 825 | 218 | 143.88
900 | 223 | 147.18 |  | 900 | 218 | 143.88
975 | 223 | 147.18 |  | 975 | 219 | 144.54
1050 | 224 | 147.84 |  | 1050 | 219 | 144.54
1125 | 222 | 146.52 |  | 1125 | 218 | 143.88
1200 | 221 | 145.86 |  | 1200 | 224 | 147.84
1275 | 222 | 146.52 |  | 1275 | 223 | 147.18
1350 | 221 | 145.86 |  | 1350 | 219 | 144.54
1425 | 222 | 146.52 |  | 1425 | 220 | 145.2
1500 | 218 | 143.88 |  | 1500 | 218 | 143.88
1575 | 220 | 145.2 |  | 1575 | 218 | 143.88
1650 | 220 | 145.2 |  | 1650 | 218 | 143.88
1725 | 227 | 149.82 |  | 1725 | 218 | 143.88
1800 | 224 | 147.84 |  | 1800 | 260 | 171.6
1875 | 221 | 145.86 |  | 1875 | 261 | 172.26
1950 | 265 | 174.9 |  | 1950 | 259 | 170.94
2025 | 219 | 144.54 |  | 2025 | 222 | 146.52
2100 | 225 | 148.5 |  | 2100 | 246 | 162.36
2175 | 221 | 145.86 |  | 2175 | 228 | 150.48
2250 | 221 | 145.86 |  | 2250 | 219 | 144.54
2325 | 224 | 147.84 |  | 2325 | 254 | 167.64
2400 | 229 | 151.14 |  | 2400 | 225 | 148.5
2475 | 227 | 149.82 |  | 2475 | 221 | 145.86
2550 | 223 | 147.18 |  | 2550 | 242 | 159.72
2625 | 259 | 170.94 |  | 2625 | 259 | 170.94
2700 | 225 | 148.5 |  | 2700 | 222 | 146.52
2775 | 218 | 143.88 |  | 2775 | 259 | 170.94
2850 | 222 | 146.52 |  | 2850 | 258 | 170.28
2925 | 222 | 146.52 |  | 2925 | 219 | 144.54
3000 | 220 | 145.2 | CAMERA OFF | 3000 | 259 | 170.94 | CAMERA OFF
3075 | 150 | 99 |  | 3075 | 147 | 97.02
3150 | 151 | 99.66 |  | 3150 | 149 | 98.34
3225 | 152 | 100.32 |  | 3225 | 146 | 96.36
3300 | 151 | 99.66 |  | 3300 | 147 | 97.02
3375 | 149 | 98.34 |  | 3375 | 146 | 96.36
3450 | 150 | 99 |  | 3450 | 149 | 98.34
3525 | 148 | 97.68 |  | 3525 | 145 | 95.7
3600 | 150 | 99 |  | 3600 | 148 | 97.68
3675 | 151 | 99.66 |  | 3675 | 147 | 97.02
3750 | 151 | 99.66 |  | 3750 | 148 | 97.68
3825 | 151 | 99.66 |  | 3825 | 145 | 95.7
3900 | 154 | 101.64 |  | 3900 | 149 | 98.34
3975 | 151 | 99.66 |  | 3975 | 149 | 98.34
4050 | 152 | 100.32 |  | 4050 | 145 | 95.7
4125 | 151 | 99.66 |  | 4125 | 144 | 95.04
4200 | 150 | 99 |  | 4200 | 145 | 95.7
4275 | 152 | 100.32 |  | 4275 | 146 | 96.36
4350 | 152 | 100.32 |  | 4350 | 147 | 97.02
4425 | 152 | 100.32 |  | 4425 | 147 | 97.02
4500 | 150 | 99 |  | 4500 | 148 | 97.68
4575 | 151 | 99.66 |  | 4575 | 146 | 96.36
4650 | 149 | 98.34 |  | 4650 | 148 | 97.68
4725 | 151 | 99.66 |  | 4725 | 145 | 95.7
4800 | 149 | 98.34 |  | 4800 | 148 | 97.68
4875 | 151 | 99.66 |  | 4875 | 145 | 95.7
4950 | 149 | 98.34 |  | 4950 | 145 | 95.7
5025 | 149 | 98.34 |  | 5025 | 144 | 95.04
5100 | 148 | 97.68 |  | 5100 | 148 | 97.68
5175 | 152 | 100.32 |  | 5175 | 148 | 97.68
5250 | 151 | 99.66 |  | 5250 | 146 | 96.36
5325 | 149 | 98.34 |  | 5325 | 148 | 97.68
5400 | 149 | 98.34 |  | 5400 | 148 | 97.68
5475 | 151 | 99.66 |  | 5475 | 145 | 95.7
5550 | 149 | 98.34 |  | 5550 | 145 | 95.7
5625 | 149 | 98.34 |  | 5625 | 145 | 95.7
5700 | 151 | 99.66 |  | 5700 | 145 | 95.7
5775 | 149 | 98.34 |  | 5775 | 149 | 98.34
5850 | 157 | 103.62 | TRANSFER | 5850 | 151 | 99.66 | TRANSFER
5925 | 160 | 105.6 |  | 5925 | 157 | 103.62
6000 | 158 | 104.28 |  | 6000 | 156 | 102.96
6075 | 160 | 105.6 |  | 6075 | 153 | 100.98
6150 | 155 | 102.3 |  | 6150 | 155 | 102.3
6225 | 155 | 102.3 |  | 6225 | 156 | 102.96
6300 | 160 | 105.6 |  | 6300 | 154 | 101.64
6375 | 159 | 104.94 |  | 6375 | 156 | 102.96
 |  | 0 |  | 6450 | 155 | 102.3
 |  | 0 |  | 6525 | 151 | 99.66
 |  | 0 |  | 6600 | 151 | 99.66
 |  | 0 |  | 6675 | 160 | 105.6
 |  | 0 |  | 6750 | 153 | 100.98
 |  | 0 |  | 6825 | 151 | 99.66
 |  | 0 |  | 6900 | 161 | 106.26
 |  | 0 |  | 6975 | 154 | 101.64
 |  | 0 |  | 7050 | 154 | 101.64
 |  | 0 |  | 7125 | 196 | 129.36
 |  | 0 |  | 7200 | 192 | 126.72
 |  | 0 |  | 7275 | 193 | 127.38
 |  | 0 |  | 7350 | 194 | 128.04
 |  | 0 |  | 7425 | 190 | 125.4
 |  | 0 |  | 7500 | 191 | 126.06
 |  | 0 |  | 7575 | 171 | 112.86
 |  | 0 |  | 7650 | 154 | 101.64
 |  | 0 |  | 7725 | 152 | 100.32
 |  | 0 |  | 7800 | 154 | 101.64
 |  | 0 |  | 7875 | 154 | 101.64
 |  | 0 |  | 7950 | 154 | 101.64
 |  | 0 |  | 8025 | 158 | 104.28
 |  | 0 |  | 8100 | 151 | 99.66
 |  | 0 |  | 8175 | 151 | 99.66
 |  | 0 |  | 8250 | 155 | 102.3
 |  | 0 |  | 8325 | 153 | 100.98

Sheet: SleepStop
RUN MODE |  |  | SLEEP MODE |  |  | Power Difference from Run Mode (mW)
Test # | Shunt Voltage (mV) | Estimated System Power (mW) | Test # | Shunt Voltage (mV) | Estimated System Power (mW) |  | Sleep | STOP0
1 | 46.95 | 96.8 | 1 | 32.75 | 60.5 | CubeMX PCC | 33.5 | 64.3
2 | 46.98 | 96.9 | 2 | 32.36 | 59.7 | Measured | 37.0 | 78.7
3 | 47 | 96.9 | 3 | 32.5 | 60.0 | Difference | 3.5 | 14.5
4 | 47.15 | 97.2 | 4 | 32.36 | 59.7
5 | 47.1 | 97.1 | 5 | 32.54 | 60.1
 | Average | 97.0 |  | Average | 60.0
 |  |  |  | Minus power from one LED as MCU light indicates SLEEP MODE
 |  |  | STOP0 MODE
 |  |  | Test # | Shunt Voltage (mV) | Estimated System Power (mW)
 |  |  | 1 | 12.3 | 18.3
 |  |  | 2 | 12.31 | 18.4
 |  |  | 3 | 12.29 | 18.3
 |  |  | 4 | 12.26 | 18.3
 |  |  | 5 | 12.23 | 18.2
 |  |  |  | Average | 18.3
 |  |  |  | Minus power from one LED as MCU light indicates SLEEP MODE

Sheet: Budget
Item | Current (mA) | Power (mW) | Source
CSA | 1 | 3.30 | Datasheet
LED |  | 10.65 | Measurement
HSE | 6 | 19.80 | Datasheet
LSE | 0.001 | 0.0033 | Datasheet
MCU (Run) | 19.6 | 64.68 | STM32CubeMX PCC | Verified by measurement
MCU (Sleep) | 9.45 | 31.18 | STM32CubeMX PCC | Verified by measurement
MCU (Stop0) | 0.125 | 0.41 | STM32CubeMX PCC | Verified by measurement
QSPI | 15 | 49.50 | Datasheet
Camera |  | 52.30 | Measurement
USB (Data) |  | 34.35 | Measurement
LDO (Max) |  | 137.12 | Calculation
LDO (Typ.) |  | 50.71 | Calculation
LDO (Low) |  | 17.39 | Calculation
LDO (Lowest) |  | 1.91 | Calculation
 | Maximum | 371.71
 | Typical | 149.15
 | Low | 82.33 | Theoretical, verified by interpolation from Sleep Test
 | Lowest | 5.62 | Excludes LED, HSE&LSE Disabled. Purely theoretical. Partially verified by STOP0 test

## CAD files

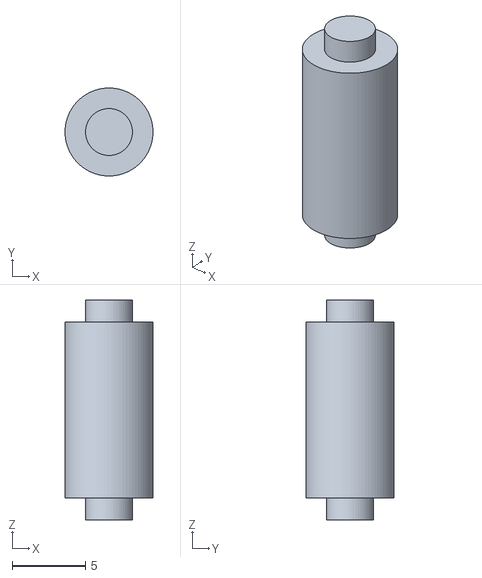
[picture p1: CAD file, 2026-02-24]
Mechanical/v0.1/C2Sv0.1 Support.stl
6.00 x 5.99 x 15.0

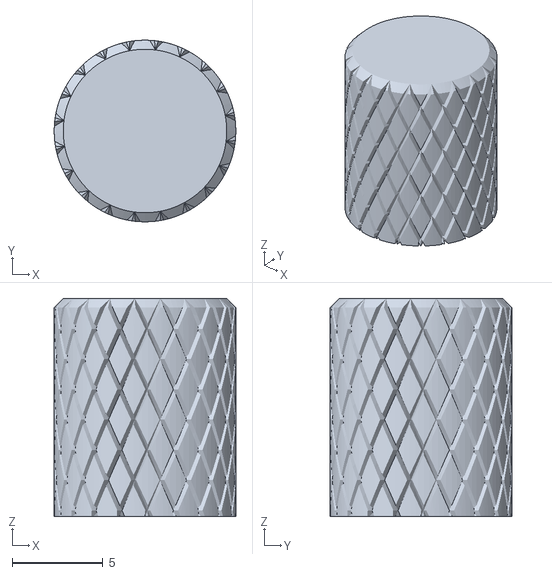
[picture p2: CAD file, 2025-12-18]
Mechanical/v0.1/C2Sv0.1 Rotary Encoder Knob.stl
10.0 x 10.0 x 12.0

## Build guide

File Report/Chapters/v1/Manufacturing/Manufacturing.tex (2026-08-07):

Only enough components were procured to assemble two PCBs entirely, using spare parts from v0.1 to save costs.
\nl
From an inventory mixup, TVS diodes and ferrite beads were not procured and were not available during assembly. I was able to use one ferrite bead and TVS diode from v0.1, and used a spare ferrite bead from EPIC (different footprint) to populate the second PCB.
As a second diode could not be found, the second PCB does not have TVS protection.
\nl
One of the PCBs was soldered with minimal bridges and the other had lots of bridges.
% TBD on this part
Both PCBs were successfully de-bridged and safe for operation.

\begin{indentedfigure}
    \centering
    \begin{subfigure}[b]{0.4\textwidth}
        \centering
        
        \caption{Processor PCB.}
        \label{fig:v1-processor-assembled}
    \end{subfigure}
    \hspace{1cm}
    \begin{subfigure}[b]{0.4\textwidth}
        \centering
        
        \caption{OV7670 Breakout PCB.}
        \label{fig:v1-breakout-assembled}
    \end{subfigure}
    \caption{C2Sv1.0 assembled PCBs.}
    \label{fig:v1-assembled}
\end{indentedfigure}

An FPC for the camera adaptor was not procured, so ten 50 mm 32 pin forward FPCs cables were procured out of pocket from AliExpress.

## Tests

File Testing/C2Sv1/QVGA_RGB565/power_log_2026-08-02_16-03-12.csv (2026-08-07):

Timestamp | Event Type | Power (mW) | Notes
2026-08-02T08:03:02.507Z | IMAGE_REQUESTED |  | Res: QVGA, Mode: RGB565
2026-08-02T08:03:02.555Z | POWER_SAMPLE | 298
2026-08-02T08:03:02.625Z | POWER_SAMPLE | 220
2026-08-02T08:03:02.695Z | POWER_SAMPLE | 220
2026-08-02T08:03:02.765Z | POWER_SAMPLE | 219
2026-08-02T08:03:02.835Z | POWER_SAMPLE | 220
2026-08-02T08:03:02.905Z | POWER_SAMPLE | 223
2026-08-02T08:03:02.975Z | POWER_SAMPLE | 222
2026-08-02T08:03:03.045Z | POWER_SAMPLE | 223
2026-08-02T08:03:03.115Z | POWER_SAMPLE | 222
2026-08-02T08:03:03.185Z | POWER_SAMPLE | 227
2026-08-02T08:03:03.255Z | POWER_SAMPLE | 223
2026-08-02T08:03:03.325Z | POWER_SAMPLE | 223
2026-08-02T08:03:03.395Z | POWER_SAMPLE | 223
2026-08-02T08:03:03.465Z | POWER_SAMPLE | 224
2026-08-02T08:03:03.535Z | POWER_SAMPLE | 222
2026-08-02T08:03:03.605Z | POWER_SAMPLE | 221
2026-08-02T08:03:03.675Z | POWER_SAMPLE | 222
2026-08-02T08:03:03.745Z | POWER_SAMPLE | 221
2026-08-02T08:03:03.815Z | POWER_SAMPLE | 222
2026-08-02T08:03:03.885Z | POWER_SAMPLE | 218
2026-08-02T08:03:03.955Z | POWER_SAMPLE | 220
2026-08-02T08:03:04.025Z | POWER_SAMPLE | 220
2026-08-02T08:03:04.095Z | POWER_SAMPLE | 227
2026-08-02T08:03:04.165Z | POWER_SAMPLE | 224
2026-08-02T08:03:04.235Z | POWER_SAMPLE | 221
2026-08-02T08:03:04.305Z | POWER_SAMPLE | 265
2026-08-02T08:03:04.375Z | POWER_SAMPLE | 219
2026-08-02T08:03:04.445Z | POWER_SAMPLE | 225
2026-08-02T08:03:04.515Z | POWER_SAMPLE | 221
2026-08-02T08:03:04.585Z | POWER_SAMPLE | 221
2026-08-02T08:03:04.655Z | POWER_SAMPLE | 224
2026-08-02T08:03:04.725Z | POWER_SAMPLE | 229
2026-08-02T08:03:04.795Z | POWER_SAMPLE | 227
2026-08-02T08:03:04.865Z | POWER_SAMPLE | 223
2026-08-02T08:03:04.935Z | POWER_SAMPLE | 259
2026-08-02T08:03:05.005Z | POWER_SAMPLE | 225
2026-08-02T08:03:05.075Z | POWER_SAMPLE | 218
2026-08-02T08:03:05.145Z | POWER_SAMPLE | 222
2026-08-02T08:03:05.215Z | POWER_SAMPLE | 222
2026-08-02T08:03:05.285Z | POWER_SAMPLE | 220
2026-08-02T08:03:05.355Z | POWER_SAMPLE | 150
2026-08-02T08:03:05.425Z | POWER_SAMPLE | 151
2026-08-02T08:03:05.495Z | POWER_SAMPLE | 152
2026-08-02T08:03:05.565Z | POWER_SAMPLE | 151
2026-08-02T08:03:05.635Z | POWER_SAMPLE | 149
2026-08-02T08:03:05.705Z | POWER_SAMPLE | 150
2026-08-02T08:03:05.775Z | POWER_SAMPLE | 148
2026-08-02T08:03:05.845Z | POWER_SAMPLE | 150
2026-08-02T08:03:05.915Z | POWER_SAMPLE | 151
2026-08-02T08:03:05.985Z | POWER_SAMPLE | 151
2026-08-02T08:03:06.055Z | POWER_SAMPLE | 151
2026-08-02T08:03:06.125Z | POWER_SAMPLE | 154
2026-08-02T08:03:06.195Z | POWER_SAMPLE | 151
2026-08-02T08:03:06.265Z | POWER_SAMPLE | 152
2026-08-02T08:03:06.335Z | POWER_SAMPLE | 151
2026-08-02T08:03:06.405Z | POWER_SAMPLE | 150
2026-08-02T08:03:06.475Z | POWER_SAMPLE | 152
2026-08-02T08:03:06.545Z | POWER_SAMPLE | 152
2026-08-02T08:03:06.615Z | POWER_SAMPLE | 152
2026-08-02T08:03:06.685Z | POWER_SAMPLE | 150
2026-08-02T08:03:06.755Z | POWER_SAMPLE | 151
2026-08-02T08:03:06.825Z | POWER_SAMPLE | 149
2026-08-02T08:03:06.895Z | POWER_SAMPLE | 151
2026-08-02T08:03:06.965Z | POWER_SAMPLE | 149
2026-08-02T08:03:07.035Z | POWER_SAMPLE | 151
2026-08-02T08:03:07.105Z | POWER_SAMPLE | 149
2026-08-02T08:03:07.175Z | POWER_SAMPLE | 149
2026-08-02T08:03:07.245Z | POWER_SAMPLE | 148
2026-08-02T08:03:07.315Z | POWER_SAMPLE | 152
2026-08-02T08:03:07.385Z | POWER_SAMPLE | 151
2026-08-02T08:03:07.455Z | POWER_SAMPLE | 149
2026-08-02T08:03:07.525Z | POWER_SAMPLE | 149
2026-08-02T08:03:07.595Z | POWER_SAMPLE | 151
2026-08-02T08:03:07.665Z | POWER_SAMPLE | 149
2026-08-02T08:03:07.735Z | POWER_SAMPLE | 149
2026-08-02T08:03:07.805Z | POWER_SAMPLE | 151
2026-08-02T08:03:07.875Z | POWER_SAMPLE | 149
2026-08-02T08:03:07.974Z | POWER_SAMPLE | 157
2026-08-02T08:03:08.038Z | POWER_SAMPLE | 160
2026-08-02T08:03:08.101Z | POWER_SAMPLE | 158
2026-08-02T08:03:08.181Z | POWER_SAMPLE | 160
2026-08-02T08:03:08.245Z | POWER_SAMPLE | 155
2026-08-02T08:03:08.323Z | POWER_SAMPLE | 155
2026-08-02T08:03:08.388Z | POWER_SAMPLE | 160
2026-08-02T08:03:08.467Z | POWER_SAMPLE | 159
2026-08-02T08:03:08.503Z | IMAGE_RENDERED |  | 320x240

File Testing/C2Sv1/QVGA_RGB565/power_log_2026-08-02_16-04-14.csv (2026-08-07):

Timestamp | Event Type | Power (mW) | Notes
2026-08-02T08:04:04.652Z | IMAGE_REQUESTED |  | Res: QVGA, Mode: RGB565
2026-08-02T08:04:04.657Z | POWER_SAMPLE | 149
2026-08-02T08:04:04.727Z | POWER_SAMPLE | 217
2026-08-02T08:04:04.797Z | POWER_SAMPLE | 215
2026-08-02T08:04:04.867Z | POWER_SAMPLE | 215
2026-08-02T08:04:04.937Z | POWER_SAMPLE | 218
2026-08-02T08:04:05.007Z | POWER_SAMPLE | 219
2026-08-02T08:04:05.077Z | POWER_SAMPLE | 218
2026-08-02T08:04:05.147Z | POWER_SAMPLE | 218
2026-08-02T08:04:05.217Z | POWER_SAMPLE | 219
2026-08-02T08:04:05.287Z | POWER_SAMPLE | 221
2026-08-02T08:04:05.357Z | POWER_SAMPLE | 218
2026-08-02T08:04:05.427Z | POWER_SAMPLE | 218
2026-08-02T08:04:05.497Z | POWER_SAMPLE | 217
2026-08-02T08:04:05.567Z | POWER_SAMPLE | 219
2026-08-02T08:04:05.637Z | POWER_SAMPLE | 218
2026-08-02T08:04:05.707Z | POWER_SAMPLE | 214
2026-08-02T08:04:05.777Z | POWER_SAMPLE | 219
2026-08-02T08:04:05.847Z | POWER_SAMPLE | 215
2026-08-02T08:04:05.918Z | POWER_SAMPLE | 222
2026-08-02T08:04:05.987Z | POWER_SAMPLE | 224
2026-08-02T08:04:06.057Z | POWER_SAMPLE | 216
2026-08-02T08:04:06.128Z | POWER_SAMPLE | 222
2026-08-02T08:04:06.197Z | POWER_SAMPLE | 218
2026-08-02T08:04:06.267Z | POWER_SAMPLE | 219
2026-08-02T08:04:06.337Z | POWER_SAMPLE | 217
2026-08-02T08:04:06.407Z | POWER_SAMPLE | 250
2026-08-02T08:04:06.478Z | POWER_SAMPLE | 224
2026-08-02T08:04:06.547Z | POWER_SAMPLE | 225
2026-08-02T08:04:06.618Z | POWER_SAMPLE | 220
2026-08-02T08:04:06.687Z | POWER_SAMPLE | 219
2026-08-02T08:04:06.757Z | POWER_SAMPLE | 216
2026-08-02T08:04:06.827Z | POWER_SAMPLE | 220
2026-08-02T08:04:06.897Z | POWER_SAMPLE | 218
2026-08-02T08:04:06.967Z | POWER_SAMPLE | 218
2026-08-02T08:04:07.037Z | POWER_SAMPLE | 247
2026-08-02T08:04:07.107Z | POWER_SAMPLE | 219
2026-08-02T08:04:07.177Z | POWER_SAMPLE | 221
2026-08-02T08:04:07.247Z | POWER_SAMPLE | 222
2026-08-02T08:04:07.317Z | POWER_SAMPLE | 221
2026-08-02T08:04:07.387Z | POWER_SAMPLE | 219
2026-08-02T08:04:07.457Z | POWER_SAMPLE | 145
2026-08-02T08:04:07.527Z | POWER_SAMPLE | 148
2026-08-02T08:04:07.597Z | POWER_SAMPLE | 147
2026-08-02T08:04:07.667Z | POWER_SAMPLE | 148
2026-08-02T08:04:07.737Z | POWER_SAMPLE | 147
2026-08-02T08:04:07.807Z | POWER_SAMPLE | 145
2026-08-02T08:04:07.877Z | POWER_SAMPLE | 146
2026-08-02T08:04:07.947Z | POWER_SAMPLE | 147
2026-08-02T08:04:08.017Z | POWER_SAMPLE | 149
2026-08-02T08:04:08.087Z | POWER_SAMPLE | 148
2026-08-02T08:04:08.157Z | POWER_SAMPLE | 145
2026-08-02T08:04:08.227Z | POWER_SAMPLE | 152
2026-08-02T08:04:08.297Z | POWER_SAMPLE | 146
2026-08-02T08:04:08.368Z | POWER_SAMPLE | 146
2026-08-02T08:04:08.438Z | POWER_SAMPLE | 147
2026-08-02T08:04:08.508Z | POWER_SAMPLE | 148
2026-08-02T08:04:08.578Z | POWER_SAMPLE | 148
2026-08-02T08:04:08.648Z | POWER_SAMPLE | 145
2026-08-02T08:04:08.718Z | POWER_SAMPLE | 147
2026-08-02T08:04:08.788Z | POWER_SAMPLE | 148
2026-08-02T08:04:08.858Z | POWER_SAMPLE | 146
2026-08-02T08:04:08.928Z | POWER_SAMPLE | 149
2026-08-02T08:04:08.998Z | POWER_SAMPLE | 146
2026-08-02T08:04:09.068Z | POWER_SAMPLE | 148
2026-08-02T08:04:09.138Z | POWER_SAMPLE | 145
2026-08-02T08:04:09.208Z | POWER_SAMPLE | 149
2026-08-02T08:04:09.278Z | POWER_SAMPLE | 147
2026-08-02T08:04:09.348Z | POWER_SAMPLE | 146
2026-08-02T08:04:09.418Z | POWER_SAMPLE | 149
2026-08-02T08:04:09.488Z | POWER_SAMPLE | 148
2026-08-02T08:04:09.558Z | POWER_SAMPLE | 147
2026-08-02T08:04:09.628Z | POWER_SAMPLE | 149
2026-08-02T08:04:09.698Z | POWER_SAMPLE | 145
2026-08-02T08:04:09.768Z | POWER_SAMPLE | 147
2026-08-02T08:04:09.838Z | POWER_SAMPLE | 148
2026-08-02T08:04:09.907Z | POWER_SAMPLE | 146
2026-08-02T08:04:09.978Z | POWER_SAMPLE | 146
2026-08-02T08:04:10.073Z | POWER_SAMPLE | 154
2026-08-02T08:04:10.138Z | POWER_SAMPLE | 156
2026-08-02T08:04:10.216Z | POWER_SAMPLE | 155
2026-08-02T08:04:10.280Z | POWER_SAMPLE | 152
2026-08-02T08:04:10.360Z | POWER_SAMPLE | 154
2026-08-02T08:04:10.423Z | POWER_SAMPLE | 160
2026-08-02T08:04:10.502Z | POWER_SAMPLE | 153
2026-08-02T08:04:10.567Z | POWER_SAMPLE | 155
2026-08-02T08:04:10.617Z | IMAGE_RENDERED |  | 320x240

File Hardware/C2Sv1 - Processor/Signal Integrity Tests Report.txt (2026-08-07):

Falling Edge Overshoot

The following nets have values outside defined tolerance levels :

Falling Edge Undershoot

The following nets have values outside defined tolerance levels :

Rising Edge Overshoot

The following nets have values outside defined tolerance levels :

Rising Edge Undershoot

The following nets have values outside defined tolerance levels :

Base Value

The following nets have values outside defined tolerance levels :
USB_D_P         (Actual Value =  213.4u , Tolerance =  0.000  )
USB_D_N         (Actual Value =  378.4u , Tolerance =  0.000  )
SWDIO           (Actual Value =  8.314u , Tolerance =  0.000  )
SPI1_SCK        (Actual Value =  10.34u , Tolerance =  0.000  )
SPI1_MOSI       (Actual Value =  27.14u , Tolerance =  0.000  )
NetQSPI_1       (Actual Value =  4.605u , Tolerance =  0.000  )
QSPI_NCS        (Actual Value =  4.605u , Tolerance =  0.000  )
NRST            (Actual Value =  17.50u , Tolerance =  0.000  )
DCMI_D2         (Actual Value =  452.7n , Tolerance =  0.000  )
NetJ5_19        (Actual Value =  452.7n , Tolerance =  0.000  )
DCMI_D5         (Actual Value =  380.4n , Tolerance =  0.000  )
NetJ5_16        (Actual Value =  380.4n , Tolerance =  0.000  )
DCMI_D6         (Actual Value =  142.6n , Tolerance =  0.000  )
NetJ5_15        (Actual Value =  142.6n , Tolerance =  0.000  )
DCMI_D7         (Actual Value =  117.1n , Tolerance =  0.000  )
NetJ5_14        (Actual Value =  117.1n , Tolerance =  0.000  )
DCMI_D8         (Actual Value =  71.69n , Tolerance =  0.000  )
NetJ5_13        (Actual Value =  71.69n , Tolerance =  0.000  )
DCMI_D9         (Actual Value =  70.69n , Tolerance =  0.000  )
NetJ5_12        (Actual Value =  70.69n , Tolerance =  0.000  )
DCMI_VSYNC      (Actual Value =  356.8n , Tolerance =  0.000  )
NetJ5_5         (Actual Value =  356.8n , Tolerance =  0.000  )
NetJ4_1         (Actual Value =  1.723u , Tolerance =  0.000  )
LSE             (Actual Value =  1.053u , Tolerance =  0.000  )
I2C2_SDA        (Actual Value =  13.05m , Tolerance =  0.000  )
I2C2_SCL        (Actual Value =  10.82m , Tolerance =  0.000  )
DCMI_GPIO2      (Actual Value =  378.3u , Tolerance =  0.000  )
DCMI_GPIO1      (Actual Value =  62.21u , Tolerance =  0.000  )

Top Value

The following nets have values outside defined tolerance levels :
TRIG            (Actual Value =  0.000  , Tolerance =  3.300  )
SPI2_SCK        (Actual Value =  0.000  , Tolerance =  3.300  )
SPI2_MOSI       (Actual Value =  0.000  , Tolerance =  3.300  )
SPI2_CS         (Actual Value =  0.000  , Tolerance =  3.300  )
NetCS_1         (Actual Value =  0.000  , Tolerance =  3.300  )
SPI1_CS         (Actual Value =  0.000  , Tolerance =  3.300  )
NetP3_2         (Actual Value =  0.000  , Tolerance =  3.300  )
SLAVE           (Actual Value =  0.000  , Tolerance =  3.300  )
CD              (Actual Value =  0.000  , Tolerance =  3.300  )
NetCD_1         (Actual Value =  0.000  , Tolerance =  3.300  )
LED_ERR         (Actual Value =  0.000  , Tolerance =  3.300  )
LED_MCU         (Actual Value =  0.000  , Tolerance =  3.300  )
Net3V3_1        (Actual Value =  0.000  , Tolerance =  3.300  )

The following nets were not able to be analysed :

TRIG
SPI2_SCK
SPI2_MOSI
SPI2_CS
NetCS_1
SPI1_CS
NetP3_2
SLAVE
CD
NetCD_1
LED_ERR
LED_MCU
Net3V3_1

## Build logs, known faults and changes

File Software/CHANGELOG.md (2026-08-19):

## RGB565 + large-frame (SD-streamed) software encoding — 2026-08-19

### Changed
- v0.1 `img_core` now encodes RGB565 (4:2:0) instead of grayscale.
- Source is streamed band-by-band from an SD file (FileX) instead of a RAM
  pointer, so frames too large for flash/RAM (up to 2560x1440) can be encoded.
  API is now `img_encode_jpeg(FX_FILE *src, ...)`.

### Notes
- SD-streamed path hardware verified on 640x480 and 2560x1440 

## Software JPEG core module — 2026-08-16

### Added
- Vendored the **JPEGENC** encoder library into both projects:
  `C2Sv1/Drivers/Custom/JPEGENC/` and `C2Sv0.1/Drivers/Custom/JPEGENC/`.
- **`img_core`** module wrapping JPEGENC. It encodes one band at a time, so
  the full frame never has to be resident in RAM:

### Verified
- Software encode on the **C2Sv0.1** board: 1024×720 grayscale at `JPEGE_Q_HIGH`
  produced a 69223 byte JPEG that decodes correctly.

### Notes
- **v1 pipeline wiring is unfinished:** Image capture → DCMI → QSPI staging →
  encode is not yet built, however the core encoder is proven from v0.1.

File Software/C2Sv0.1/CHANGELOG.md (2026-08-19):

# Changelog

## RGB565 hardware JPEG encoding, streamed from SD

### Changed
- `jpeg_codec` now encodes RGB565 as YCbCr 4:2:0 (was grayscale), via the
  hardware codec + `jpeg_utils` RGB->MCU conversion; new API `JPEG_Encode_RGB`.
- Source is streamed band-by-band from an SD file (FileX), so frames too large
  for flash/RAM (up to 2560x1440) can be encoded. `JPEG_RGB_FORMAT` set to
  `JPEG_RGB565` in `jpeg_utils_conf.h`.

### Notes
- Hardware verified

## Stream JPEG encoding band-by-band to support high-quality image inputs

### Added
- HAL_JPEG_GetDataCallback feeds the codec one band at a time via HAL_JPEG_ConfigInputBuffer.
- JPEG_Encode_Progress state struct + MAX_WIDTH image dimension bound.

### Changed
- 'JPEG_Encode_Gray' no longer tiles the whole frame into a 128x128 'mcu_buf'.

### Notes
- Still a static test image and harness, no live DCMI capture.
- Verified on board

## Fix JPEG encoded-length reporting

### Fixed
- `JPEG_Encode_Gray` reported `*out_len` from `hjpeg->OutDataLength` — the output
  buffer capacity (~20000), not the real compressed size, so SD files were
  written padded to the full buffer. The true length is now accumulated from
  `HAL_JPEG_DataReadyCallback` into a file-scope counter (reset before each
  encode) and returned via `*out_len`.
- `main.c`: `JEPG_OUT_CAP` → `JPEG_OUT_CAP` macro typo.

### Notes
- Verified on hardware

## Finalise v0.1 JPEG Encoding

### Added
- `jpeg_codec.c/.h` — grayscale JPEG encoder wrapping the STM32U5G9 hardware
  codec: configures the codec (size/quality/grayscale), tiles the raster image
  into 8x8 MCU blocks, runs a blocking encode, reports the compressed length,
  and guards both HAL calls.
- Copied in `jpeg_utils.c/.h` + `jpeg_utils_conf.h` (for the future RGB path).
- Pre-captured 128x128 grayscale test image into a `const` header to be used as encoder input.

### Changed
- `main.c` now calls `JPEG_Encode_Gray(...)` in place of the inline `HAL_JPEG_*`
  test; the SD write uses the returned `jpeg_size`.
- Replaced the synthetic stripe pattern with the pre-captured test image.

### Fixed
- `.gitignore` bug: the version directory's contents are now excluded
  (`/*`) with Core `Inc`/`Src`/`Startup` re-includes, so `Drivers/Custom` and Core
  sources are actually tracked instead of ignored.

### Notes
- Not yet hardware-verified. 
- No camera to encoding pipeline set up yet, only uses a pre-generated test image.

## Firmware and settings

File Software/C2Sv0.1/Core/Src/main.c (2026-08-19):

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
/* Includes ------------------------------------------------------------------*/
#include "main.h"
#include "jpeg_utils_conf.h"
#include "app_filex.h"
#include "jpeg_codec.h"
#include "test_image.h"

/* USER CODE BEGIN PD */

#define SAMPLE_PERIOD_MS 50
#define POWER_AVG_WINDOW_MS 1000

#define ENCODER_VAL scroll_encoder.cfg.arr[scroll_encoder.cfg.idx]

/* USER CODE END PD */

ADC_HandleTypeDef hadc1;

DCMI_HandleTypeDef hdcmi;
DMA_HandleTypeDef handle_GPDMA1_Channel11;

I2C_HandleTypeDef hi2c1;
I2C_HandleTypeDef hi2c2;
I2C_HandleTypeDef hi2c4;

JPEG_HandleTypeDef hjpeg;

OSPI_HandleTypeDef hospi1;

RTC_HandleTypeDef hrtc;

SD_HandleTypeDef hsd1;

SPI_HandleTypeDef hspi1;

USART_HandleTypeDef husart1;
USART_HandleTypeDef husart2;

/* USER CODE BEGIN PV */

// Scoll Encoder
Encoder_HandleTypeDef scroll_encoder;
int BOOT0 = 0;

// Current Sense Amplifier (CSA) Variables
CSA_HandleTypeDef csa;
uint32_t prevTime = 0;
float powerSum = 0;
float powerAvg = 0;
float currentSum = 0;
float voltageSum = 0;
float currentAvg = 0;
float voltageAvg = 0;
uint32_t sampleCount = 0;

// OCTOSPI
QSPI_HandleTypeDef QSPI_Memory;
QSPI_DataChunk_HandleTypeDef DataChunk;
OSPI_RegularCmdTypeDef sCommand;

// Image Sensor
uint16_t sensor_temp = 0;

#define JPEG_OUT_CAP (512 * 1024)
uint32_t jpeg_size = 0;
static uint8_t jpeg_out[JPEG_OUT_CAP];


/* USER CODE END PV */

void SystemClock_Config(void);
static void MX_GPIO_Init(void);
static void MX_GPDMA1_Init(void);
static void MX_ADC1_Init(void);
static void MX_I2C4_Init(void);
static void MX_OCTOSPI1_Init(void);
static void MX_SPI1_Init(void);
static void MX_I2C1_Init(void);
static void MX_JPEG_Init(void);
static void MX_DCMI_Init(void);
static void MX_I2C2_Init(void);
static void MX_USART1_Init(void);
static void MX_USART2_Init(void);
static void MX_RTC_Init(void);
/**
  * @brief  The application entry point.
  * @retval int
  */
int main(void)
{

  /* MCU Configuration--------------------------------------------------------*/

  /* Reset of all peripherals, Initializes the Flash interface and the Systick. */
  HAL_Init();

  /* Configure the system clock */
  SystemClock_Config();

  /* Initialize all configured peripherals */
  MX_GPIO_Init();
  MX_GPDMA1_Init();
  MX_ADC1_Init();
  MX_I2C4_Init();
  MX_OCTOSPI1_Init();
  MX_SPI1_Init();
  MX_I2C1_Init();
  MX_SDMMC1_SD_Init();
  MX_JPEG_Init();
  MX_DCMI_Init();
  MX_I2C2_Init();
  MX_USART1_Init();
  MX_USART2_Init();
  MX_FileX_Init();
  MX_RTC_Init();
  /* USER CODE BEGIN 2 */

  // Compatability Check
  if (VERIFY_CFG == 1) {
	  // compat check
  }



  // Initialise subsystems

// Image Sensor
	  JPEG_Encode_Gray(&hjpeg, test_image, 1024, 720, 30, jpeg_out, sizeof(jpeg_out), &jpeg_size);
	  uSD_Init();
	  SD_Stream_Data("testimg.jpg", jpeg_out, jpeg_size, 1);
//	  AR_Init_Temperature(&hi2c1);
//	  AR_Read_Temperature(&hi2c1, &sensor_temp);
//	  AR_Init_ImageSensor(&hi2c1);


  	  // Test microSD writing
//	  HAL_Delay(2000);
//	  Test_Image_Stream();

	  // Current Sense Amplifier
	  CSA_Init(&csa, SHUNT_RESISTANCE, 3.3f, 5.0f, 50);

	  // LEDs
	  LED_CONFIGURE_GND();

	  // Rotary Encoder
	  Encoder_Init(&scroll_encoder, SCROLL_A_GPIO_Port, SCROLL_A_Pin,
					   SCROLL_B_GPIO_Port, SCROLL_B_Pin);
	  // LCD Screen
	  if (SELECTED_LCD) { sLCD_Init(&hi2c4); }

	  // QSPI Memory
	  QSPI_Init_Memory(&hospi1, &sCommand, &QSPI_Memory);

	  // OCTOSPI
//	  QSPI_Init_DataBlock(&DataChunk, sizeof(tx_str), tx_str, rx_str);
//	  QSPI_Write_Data(&QSPI_Memory, &DataChunk);
//	  QSPI_Read_Data(&QSPI_Memory, &DataChunk);
//	  QSPI_Erase_Data(&QSPI_Memory, &DataChunk);


  /* USER CODE END 2 */

  /* Infinite loop */
  /* USER CODE BEGIN WHILE */
  while (1)
  {
	  // Update LEDs
	  LED_SyncEncoder(ENCODER_VAL);

	  // Update and get CSA voltage
	  CSA_Update(&csa, &hadc1);

	  // Delay
	  HAL_Delay(SAMPLE_PERIOD_MS);

	  // Read BOOT0 Pin State
	  BOOT0 = HAL_GPIO_ReadPin(BOOT0_GPIO_Port, BOOT0_Pin);

	  powerSum   += csa.sys_power;
	  currentSum += csa.current;
	  voltageSum += csa.voltage;
	  sampleCount++; // Track real number of samples

	  uint32_t now = HAL_GetTick();
	  if ((now - prevTime) >= POWER_AVG_WINDOW_MS && sampleCount > 0) {
	      // Use 64-bit math to prevent overflow and maintain precision
	      powerAvg   = (uint32_t)((powerSum * 1000) / sampleCount);
	      currentAvg = (uint32_t)((currentSum * 1000) / sampleCount);
	      voltageAvg = (uint32_t)((voltageSum * 1000) / sampleCount);

	      // Reset
	      powerSum = 0; currentSum = 0; voltageSum = 0;
	      sampleCount = 0;
	      prevTime = now;
	  }

	  float lcd_vals[3] = {powerAvg, currentAvg, voltageAvg};
	  if (SELECTED_LCD) { sLCD_CSA_DISPLAY(scroll_encoder.cfg.idx, lcd_vals); }



    /* USER CODE END WHILE */

    /* USER CODE BEGIN 3 */
  }
  /* USER CODE END 3 */
}

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


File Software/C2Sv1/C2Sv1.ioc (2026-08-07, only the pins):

Mcu.UserName=STM32U575RITx
PA1.Signal=SPI1_SCK
PA10.GPIO_Label=SPI1_CS
PA10.Signal=GPIO_Input
PA11.Signal=USB_OTG_FS_DM
PA12.Signal=USB_OTG_FS_DP
PA2.Signal=OCTOSPIM_P1_NCS
PA3.Signal=OCTOSPIM_P1_CLK
PA4.Signal=DCMI_HSYNC
PA5.GPIO_Label=DCMI_GPIO0
PA5.Signal=GPIO_Output
PA6.Signal=DCMI_PIXCLK
PA7.Signal=SPI1_MOSI
PA8.GPIO_Label=DCMI_MCLK
PA8.Signal=RCC_MCO
PA9.GPIO_Label=WAKEUP
PA9.Signal=GPXTI9
PB0.GPIO_Label=DCMI_GPIO3
PB0.Signal=GPIO_Output
PB10.Signal=I2C2_SCL
PB14.Signal=I2C2_SDA
PB6.Signal=DCMI_D5
PB7.Signal=DCMI_VSYNC
PB8.Signal=DCMI_D6
PB9.Signal=DCMI_D7
PC0.Signal=OCTOSPIM_P1_IO7
PC1.Signal=OCTOSPIM_P1_IO4
PC11.Signal=DCMI_D4
PC13.GPIO_Label=SHUTTER
PC13.Signal=GPXTI13
PC2.Signal=OCTOSPIM_P1_IO5
PC3.Signal=OCTOSPIM_P1_IO6
PC4.GPIO_Label=DCMI_GPIO1
PC4.Signal=GPIO_Output
PC5.GPIO_Label=DCMI_GPIO2
PC5.Signal=GPIO_Output
PC6.Signal=DCMI_D0
PC7.Signal=DCMI_D1
PC8.Signal=DCMI_D2
PC9.Signal=DCMI_D3

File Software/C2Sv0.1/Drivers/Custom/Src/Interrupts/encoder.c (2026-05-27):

/*
 * encoder.c
 *
 *  Created on: Dec 13, 2025
 *      Author: felix
 */

#include "encoder.h"

// Static encoder instance (one encoder example)
extern int selected_mode;
extern Encoder_HandleTypeDef scroll_encoder;

// -------------------------- Internal functions ---------------------------

/**
 * @brief Updates the rotary encoder state machine.
 *
 * Processes encoder transitions based on the triggering GPIO pin and edge
 * direction. Detects clockwise (CW) and counterclockwise (CCW) detents
 * and updates the active configuration value accordingly.
 *
 * @param encoder Pointer to the encoder handle structure.
 * @param GPIO_Pin GPIO pin that triggered the interrupt.
 * @param rising 1 if rising edge, 0 if falling edge.
 */
void Encoder_Update(Encoder_HandleTypeDef *encoder, uint16_t GPIO_Pin, uint8_t rising)
{
    // Read instantaneous encoder channel states
    encoder->enc_a = HAL_GPIO_ReadPin(encoder->pinA_port, encoder->pinA);
    encoder->enc_b = HAL_GPIO_ReadPin(encoder->pinB_port, encoder->pinB);

    // Expected clockwise transition sequence
    static const uint8_t CW_sequence[4][2] = {
        {0, 1}, {1, 1}, {0, 0}, {1, 0}
    };

    // Expected counterclockwise transition sequence
    static const uint8_t CCW_sequence[4][2] = {
        {1, 1}, {0, 1}, {1, 0}, {0, 0}
    };

    // Check clockwise transition
    if (GPIO_Pin == encoder->pinA &&
        rising == CW_sequence[encoder->step][1])
    {
        encoder->step++;
        if (encoder->step >= 4)
        {
            if (encoder->cfg.arr[encoder->cfg.idx] < 15)
            {
                encoder->cfg.arr[encoder->cfg.idx]++; // One CW detent
            }
            encoder->step = 0;
        }
        return;
    }

    // Check counterclockwise transition
    if (GPIO_Pin == encoder->pinB &&
        rising == CCW_sequence[encoder->step][1])
    {
        encoder->step++;
        if (encoder->step >= 4)
        {
            if (encoder->cfg.arr[encoder->cfg.idx] > 0)
            {
                encoder->cfg.arr[encoder->cfg.idx]--; // One CCW detent
            }
            encoder->step = 0;
        }
        return;
    }

    // Invalid transition, reset state machine
    encoder->step = 0;
}


/**
 * @brief Initialises the encoder handle structure.
 *
 * Configures GPIO ports and pins for encoder channels A and B,
 * resets internal state variables, and initialises the associated
 * settings structure.
 *
 * @param encoder Pointer to the encoder handle structure.
 * @param pinA_port GPIO port for channel A.
 * @param pinA GPIO pin for channel A.
 * @param pinB_port GPIO port for channel B.
 * @param pinB GPIO pin for channel B.
 */
void Encoder_Init(Encoder_HandleTypeDef *encoder,
                  GPIO_TypeDef* pinA_port, uint16_t pinA,
                  GPIO_TypeDef* pinB_port, uint16_t pinB)
{
    encoder->enc_a = 0;
    encoder->enc_b = 0;
    encoder->step = 0;
    encoder->pinA_port = pinA_port;
    encoder->pinA = pinA;
    encoder->pinB_port = pinB_port;
    encoder->pinB = pinB;

    // Initialise configuration settings
    Encoder_Settings_Init(&(encoder->cfg));
}


/**
 * @brief Initialises the encoder configuration settings.
 *
 * Sets the number of configurable settings, initial index,
 * and clears all stored setting values.
 *
 * @param cfg Pointer to the settings handle structure.
 */
void Encoder_Settings_Init(Settings_HandleTypeDef *cfg)
{
    cfg->num = MAX_SETTINGS;
    cfg->idx = STARTING_SETTING;

    for (int i = 0; i < MAX_SETTINGS; i++)
    {
        cfg->arr[i] = 0;
    }
}


/**
 * @brief Returns the currently selected encoder value.
 *
 * Provides access to the active setting value for external modules.
 *
 * @return Current setting value.
 */
int8_t Encoder_GetValue(void)
{
    return scroll_encoder.cfg.arr[scroll_encoder.cfg.idx];
}

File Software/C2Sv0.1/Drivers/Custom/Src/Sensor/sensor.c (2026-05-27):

/*
 * sensor.c
 *
 *  Created on: Mar 7, 2026
 *      Author: felix
 *
 *  Functions are named according to purpose [DRIVER]_[OEPRATION]_[OBJECT]
 *  	DRIVER: What the function is for, in this case, AR0141CS
 *  	OPERATION: Read, Write, Reset, etc.
 *  	OBJECT: What it is operating on
 *
 */

#include "sensor.h"

/**
  * @brief  Initialises all subsystems of the AR0141CS image sensor
  *
  * @param  *hi2c I2C HAL handle
  *
  * @retval Confirmation of operation, HAL_OK for successful, HAL_ERROR for unsuccessful
  */
HAL_StatusTypeDef AR_Init_ImageSensor(I2C_HandleTypeDef *hi2c)
{
	if (AR_Init_Clock(hi2c) != HAL_OK) return HAL_ERROR;
	if (AR_Init_Temperature(hi2c) != HAL_OK) return HAL_ERROR;
	if (AR_Init_Parallel(hi2c) != HAL_OK) return HAL_ERROR;

	return HAL_OK;
}

/**
  * @brief  Writes data to a specified address
  *
  * @param  *hi2c I2C HAL handle
  * @param  reg_addr Address of the data register
  * @param	*pData Pointer to data
  *
  * @retval Confirmation of operation, HAL_OK for successful, HAL_ERROR for unsuccessful
  */
HAL_StatusTypeDef AR_Write_Register(I2C_HandleTypeDef *hi2c, uint16_t reg_addr, uint16_t *pData)
{
	uint8_t packet_size = 4;
	uint8_t packet[packet_size];

	// (MSB first)
	packet[0] = (reg_addr >> 8) & 0xFF;
	packet[1] = reg_addr & 0xFF;
	packet[2] = (uint8_t)(*pData >> 8);
	packet[3] = (uint8_t)(*pData & 0xFF);

	// Address must be 7 bits
	return HAL_I2C_Master_Transmit(hi2c, AR_SLAVE_WRITE_LOW, packet, packet_size, AR_TIMEOUT_GENERAL);
}

/**
  * @brief  Writes data to a specified address
  *
  * @param  *hi2c I2C HAL handle
  * @param  reg_addr Address of the data register
  * @param	*pData Pointer to data
  *
  * @retval Confirmation of operation, HAL_OK for successful, HAL_ERROR for unsuccessful
  */
HAL_StatusTypeDef AR_Read_Register(I2C_HandleTypeDef *hi2c, uint16_t reg_addr, uint16_t *pData)
{
    uint8_t addr_buf[2];
    uint8_t data_buf[2];

    addr_buf[0] = (reg_addr >> 8) & 0xFF;
    addr_buf[1] = reg_addr & 0xFF;

    // 1. Write the register address pointer
    if (HAL_I2C_Master_Transmit(hi2c, AR_SLAVE_WRITE_LOW << 1, addr_buf, 2, AR_TIMEOUT_GENERAL) != HAL_OK) return HAL_ERROR;

    // 2. Read the 16-bit response (LSB automatically set to 1)
    if (HAL_I2C_Master_Receive(hi2c, AR_SLAVE_READ_LOW, data_buf, 2, AR_TIMEOUT_GENERAL) == HAL_OK) {
        *pData = (uint16_t)(data_buf[0] << 8) | data_buf[1];
        return HAL_OK;
    }

    return HAL_ERROR;
}

/**
  * @brief  Initialises the internal temperature sensor registers
  *
  * @param  *hi2c I2C HAL handle
  *
  * @retval Confirmation of operation, HAL_OK for successful, HAL_ERROR for unsuccessful
  */
HAL_StatusTypeDef AR_Init_Temperature(I2C_HandleTypeDef *hi2c)
{
	uint16_t reg_data;
	// Read existing config so we don't destroy other settings
	if (AR_Read_Register(hi2c, AR_TEMP_REGISTER_INPUT, &reg_data) == HAL_OK) {
	    if ((reg_data & 0x11) != 0x11) { // If the register has not already been set

	    	reg_data |= (1U << 0) | (1U << 4);

		    return AR_Write_Register(hi2c, AR_TEMP_REGISTER_INPUT, &reg_data);
	    }
	}
	return HAL_ERROR;
}

/**
  * @brief  Reads the internal die temperature sensor
  *
  * @param  *hi2c I2C HAL handle
  * @param	*pData Pointer to data
  *
  * @retval Confirmation of operation, HAL_OK for successful, HAL_ERROR for unsuccessful
  */
HAL_StatusTypeDef AR_Read_Temperature(I2C_HandleTypeDef *hi2c, uint16_t *pData)
{
	uint16_t temp_adc;
	// Read data from R0x30B2[0:0]
	if (AR_Read_Register(hi2c, AR_TEMP_REGISTER_OUTPUT, &temp_adc) != HAL_OK) return HAL_ERROR;
	// Mask bits [9:0]
	temp_adc &= 0x3FF;
	// Calculate temperature
	*(pData) = temp_adc * AR_TEMP_SLOPE + AR_TEMP_OFFSET;  // Need to adjust to account for float rounding

	return HAL_OK;
}

/**
  * @brief  Writes to the mirror image register
  * 		Enables/disables different mirroring options
  * 		Horizontal set on 0x3040[14], vertical set on 0x3040[15]
  *
  *	Could be optimised by checking the register before writing.
  *
  * @param  *hi2c I2C HAL handle
  * @param	state Mirror state: 0x00 (no mirror), 0b01 (horizontal mirror), 0b10 (vertical mirror), 0b11 (horiz. & vert. mirror)
  *
  * @retval Confirmation of operation, HAL_OK for successful, HAL_ERROR for unsuccessful
  */
HAL_StatusTypeDef AR_Write_Mirror(I2C_HandleTypeDef *hi2c, uint8_t state)
{
	uint16_t reg_data;

	uint16_t h_bit = (uint16_t)(state & 0b01);       	// Get bit 0
	uint16_t v_bit = (uint16_t)((state & 0b10) >> 1); 	// Get bit 1 and move to position 0

	if (AR_Read_Register(hi2c, AR_MIRROR_REGISTER, &reg_data) == HAL_OK) {
		// Clear ONLY bits 14 and 15
		reg_data &= ~((1U << 14) | (1U << 15));

		// Horizontal and Vertical bits
		reg_data |= (h_bit << 14);
		reg_data |= (v_bit << 15);
		return AR_Write_Register(hi2c, AR_MIRROR_REGISTER, &reg_data);
	}
	return HAL_ERROR;
}

/**
  * @brief  Initialises the internal clock dividers and multipliers
  *
  * @param  *hi2c I2C HAL handle
  *
  * @retval Confirmation of operation, HAL_OK for successful, HAL_ERROR for unsuccessful
  */
HAL_StatusTypeDef AR_Init_Clock(I2C_HandleTypeDef *hi2c)
{
	float fVCO = AR_CLK_EXTCLK / AR_CLK_PLLDIV * AR_CLK_PLLMULT;
	float fOUT = fVCO / AR_CLK_SYSDIV / AR_CLK_PIXDIV;

	// 1. External Clock: 6-50 MHz
	if (AR_CLK_EXTCLK < 6 || AR_CLK_EXTCLK > 50) return HAL_ERROR;
	// 2. Pre-PLL Divider: 1-64
	if (AR_CLK_PLLDIV < 1 || AR_CLK_PLLDIV > 64) return HAL_ERROR;
	// 3. PLL Multiplier: 32-384
	if (AR_CLK_PLLMULT < 32 || AR_CLK_PLLMULT > 384) return HAL_ERROR;
	// 4. System Divider: Must be 1 OR (Even between 2-16)
	if (AR_CLK_SYSDIV != 1 && (AR_CLK_SYSDIV % 2 != 0 || AR_CLK_SYSDIV > 16)) return HAL_ERROR;
	// 5. Pixel Divider: 4-16
	if (AR_CLK_PIXDIV < 4 || AR_CLK_PIXDIV > 16) return HAL_ERROR;
	// 6. Frequency Limits
	if (fVCO < AR_CLK_MAXF || fVCO > 768.0f) return HAL_ERROR;
	if (fOUT > AR_CLK_MINVCO) return HAL_ERROR;

	// I DON'T KNOW WHAT REGISTER TO WRITE TO

//	// Read existing config so we don't destroy other settings
//	uint16_t reg_data;
//	uint8_t h_state = (state & 0x01);
//	uint8_t v_state = (state & 0x10) >> 5;
//
//	if (AR_Read_Register(hi2c, AR_MIRROR_REGISTER, &reg_data) == HAL_OK) {
//		// Clear the bit status
//		reg_data &= ~(1U << 0);
//		reg_data &= ~(1U << 15);
//		// Horizontal and Vertical bits
//		reg_data |= (uint16_t)(h_state << 0);
//		reg_data |= (uint16_t)(v_state << 15);
//		return AR_Write_Register(hi2c, AR_MIRROR_REGISTER, &reg_data);
//	}
	return HAL_ERROR;
}
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

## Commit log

2026-05-06 Reformatting repo structure. Adding in LaTeX document for version control. Adding in Altium hardware docs. Added preliminary research LaTeX doc.
    [ADCS C2Sv0.1 - Processor.PrjPcb, ADCS C2Sv0.1 - Sensor.PrjPcb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]
2026-05-07 Wrote OV7670 mounting content, silkscreen, routing.
2026-05-10 Updated CSA shunt resistor value. Made note of no CSA and OV7670 address clash.
2026-08-07 Merge Doc into Development
    **Branch:** Doc
    **Related Issue:** N/A
    **Summary:**
    Integrates documentation changes and brings previous branch structure in-line with the team's GitHub standards.
    **Changes Made:**
    - Changed PPCC to C2I for clarity -> updated TOA, PCB connector diagram.
    - Updated .gitignore to track LaTeX images folder only.
    - Added remarks to v1.0 hardware. Prepped structure for software. Made preliminary notes on manufacturing.
    - Updated report to reflect updates from C2Sv1 programming as of 26/07/26
2026-08-07 Merge Software into Development
    **Branch:** Software
    Merges work done on the project's software and hardware with the Development branch and brings previous branch structure in-line with the team's GitHub standards.
    * Changed PPCC to C2I for clarity -> updated TOA, PCB connector diagram.
    * Updated .gitignore to track LaTeX images folder only.
    * Added C2Sv1 CubeIDE project and imported custom libraries/drivers from v0.1 (libraries not updated to fit v1 requirements).
    * Re-linked project, startup and I/O files generated. LEDs blink successfully.
    * Interrupt configured on shutter button and rising/falling functions redefined in interr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
    [ADCS C2Sv1.sdf, ADCS C2Sv1_2026-05-10T05_36_22_UTC.PrjPcb, C2Sv1 OV7670 Breakout.PcbDoc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]
2026-08-19 Feature/16/core software compression module (#36)
    * Interrupt configured on shutter button and rising/falling functions redefined in interrupt.c/h
    * QSPI configured and read Jedec ID
    * INA219 developed and functional. Reads current in mA and power in mW. Abstracted into struct and ReadAll functions.
    * Introduced FileX. No build clash between TinyUSB and Fil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
2026-08-19 Enhancement/24/improve image quality support
    **Branch:** Enhancement/24/improve image quality support
    **Related Issue:** Closes #24
    Added support for RGB and compressing higher quality images (up to 2560x1440).
    * Added JPEG codec scaffold (v0.1) and fixed .gitignore to track jpeg util drivers
    * Implemented full JPEG codec wrapper in jpeg_codec.c
    * Wired JPEG codec wrapper into main
    * created test image stored as const in header. Removed old synthetic stripe image
    * README and CHANGELOG written
    * gitignore change
    * bug(23): modified jpeg_codec.c to report true encoded size via DataReadyCallback
    * enhancement(24): Improved input image quality capabil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
    [AT25SF2561C.c, AT25SF2561C.h, jpeg_codec.c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]

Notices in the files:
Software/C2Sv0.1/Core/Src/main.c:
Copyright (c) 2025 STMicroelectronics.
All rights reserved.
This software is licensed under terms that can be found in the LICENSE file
